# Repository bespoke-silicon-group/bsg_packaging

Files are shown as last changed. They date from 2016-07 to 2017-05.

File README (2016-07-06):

In this directory are a bunch of subdirectories, one for each unique package.

Currently there are two packages:

gf
ucsd_bga_332

There is also the common directory, which contains files for constructing padrings, 
including portability files for each process (e.g. tsmc 250) being targeted.

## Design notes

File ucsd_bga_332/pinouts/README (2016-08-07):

A package is generally a passive component with physical geometry, 
basically a set of electrically connected substrate bond pad (SBP) locations, 
and corresponding connections to pins or balls. 

It does not necessarily say anything about the whether those pins
are inputs or outputs, and it could change based on the use of the package.

We call a package combined with this information a "pinout". This 
directory is for holding pinout-specific files.

Currently, we just have the bsg_one pinout, and bsg_two.

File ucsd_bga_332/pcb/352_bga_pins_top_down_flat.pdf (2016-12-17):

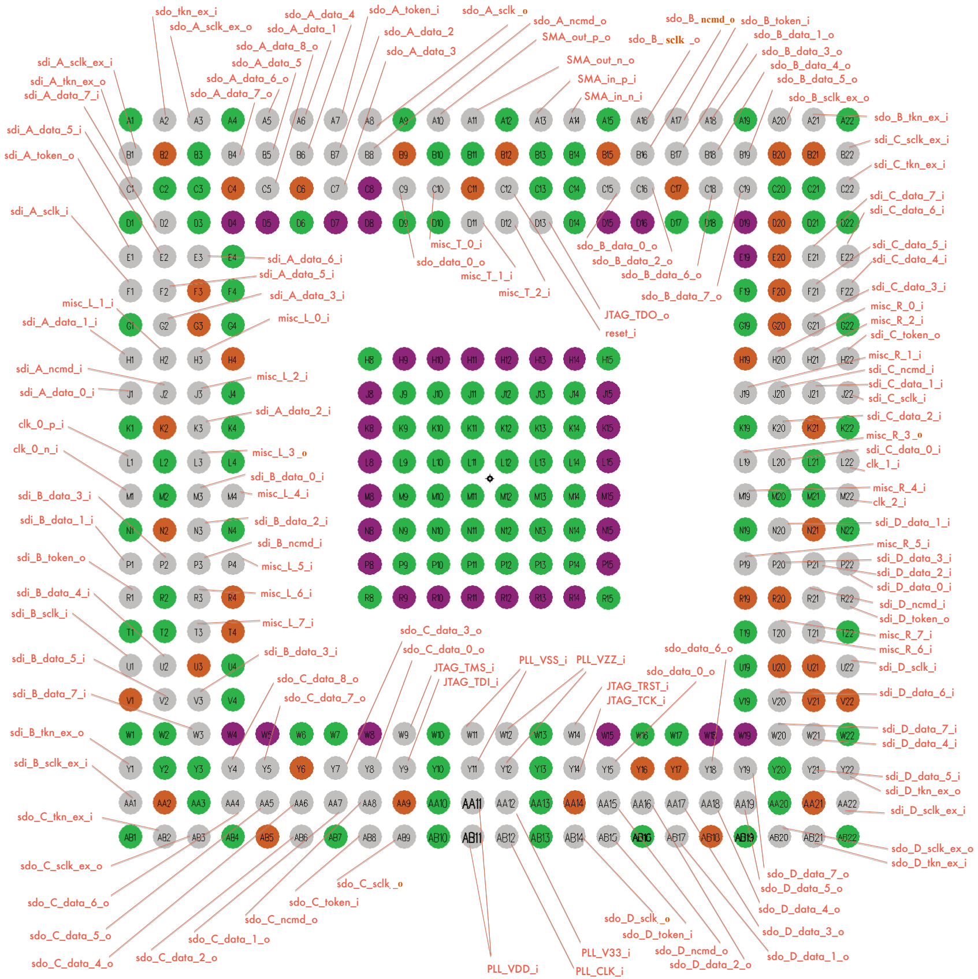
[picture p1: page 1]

sdo_B_tkn_ex_i
sdi_C_sclk_ex_i

sdi_C_tkn_ex_i

sdi_C_data_7_i
sdi_C_data_6_i

sdi_C_data_5_i
sdi_C_data_4_i

sdi_C_data_3_i
misc_R_0_i
misc_R_2_i
sdi_C_token_o
misc_R_1_i
sdi_C_ncmd_i
sdi_C_data_1_i
sdi_C_sclk_i
sdi_C_data_2_i
misc_R_3_i
sdi_C_data_0_i
clk_1_i
misc_R_4_i
clk_2_i
sdi_D_data_1_i
misc_R_5_i
sdi_D_data_3_i
sdi_D_data_2_i
sdi_D_data_0_i
sdi_D_ncmd_i
sdi_D_token_o
misc_R_7_i
misc_R_6_i
sdi_D_sclk_i

sdi_D_data_6_i

sdi_D_data_7_i
sdi_D_data_4_i

sdi_D_data_5_i
sdi_D_tkn_ex_o
sdi_D_sclk_ex_i

sdo_D_sclk_ex_o
sdo_D_tkn_ex_i

sdo_C_data_7_o

sdo_C_data_8_o

sdo_data_6_o
sdo_data_0_o
JTAG_TRST_i
JTAG_TCK_i

PLL_VSS_i PLL_VZZ_i JTAG_TMS_i JTAG_TDI_i

sdo_C_data_0_o

sdo_C_data_3_o

sdo_D_data_7_o
sdo_D_data_5_o

sdo_B_data_7_o

sdo_B_data_6_o

sdo_B_data_2_o

sdo_B_data_0_o

sdo_B_sclk_ex_o

sdo_B_data_3_o

sdo_B_data_5_o

sdo_B_data_4_o

sdo_B_data_1_o

sdo_B_token_i
sdo_B_ncmd_o

sdo_B_sclk_i

SMA_in_n_i

SMA_in_p_i

SMA_out_n_o

SMA_out_p_o

sdo_A_sclk_i
sdo_A_ncmd_o

sdo_A_token_i
sdo_A_data_2
sdo_A_data_3

sdo_A_data_4
sdo_A_data_1

sdo_A_data_5
sdo_A_data_6_o

sdo_A_data_8_o

sdo_A_data_7_o

sdo_A_sclk_ex_o

sdo_tkn_ex_i

JTAG_TDO_o
reset_i

misc_T_2_i

misc_T_1_i

misc_T_0_i
sdo_data_0_o

sdi_A_sclk_ex_i
sdi_A_tkn_ex_o
sdi_A_data_7_i

sdi_A_data_6_i

sdi_A_data_5_i

sdi_A_token_o

sdi_A_data_5_i

sdi_A_sclk_i

sdi_A_data_3_i

sdi_A_data_1_i

misc_L_1_i
misc_L_0_i

misc_L_2_i sdi_A_ncmd_i
sdi_A_data_0_i
sdi_A_data_2_i
clk_0_p_i
clk_0_n_i | misc_L_3_i
| misc_L_4_i

sdi_B_data_0_i

sdi_B_data_2_i

sdi_B_data_3_i

sdi_B_data_1_i
sdi_B_ncmd_i
misc_L_5_i sdi_B_token_o

misc_L_6_i
misc_L_7_i sdi_B_sclk_i

sdi_B_data_4_i

sdi_B_data_5_i | sdi_B_data_3_i

sdi_B_data_7_i

sdi_B_tkn_ex_o

sdi_B_sclk_ex_i

sdo_C_tkn_ex_i

sdo_C_sclk_ex_o

sdo_C_data_6_o

sdo_C_data_5_o
sdo_C_data_4_o sdo_C_data_2_o sdo_C_data_1_o

sdo_C_ncmd_o

sdo_C_token_i

sdo_C_sclk_i

sdo_D_data_4_o
sdo_D_data_3_o

sdo_D_data_1_o sdo_D_data_2_o

sdo_D_ncmd_o

sdo_D_token_i

sdo_D_sclk_i

PLL_CLK_i

PLL_V33_i
PLL_VDD_i

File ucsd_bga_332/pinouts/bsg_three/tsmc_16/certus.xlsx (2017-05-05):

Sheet: MPW2
Order | Approx | Fixed I/O | Fixed I/O Name | Top Row (→) | Left (↑) | Bottom (←) | Right (↓)
1 | 48.09230769 | DVDD | DVDD_1 | DVDD_T_1 | DVDD_L_1 | DVDDTIE_B_1 | DVDD_R_8
2 | 96.18461538 | DVSS | DVSS_1 | DVSS_T_1 | DVSS_L_1 | DVSS_B_1 | DVSS_R_8 | Notes:
3 | 144.2769231 | VDD | VDD_1 | VDD_T_1 | VDD_L_1 | VDD_B_1 | VDD_R_10 | 1) Removed JTAG on the bottom due to congestion. Moved to the Right side
4 | 192.3692308 | VSS | VSS_1 | VSS_T_1 | VSS_L_1 | VSS_B_1 | VSS_R_10 | 2) PG pairs cannot be "moved" due to fixed bump routing
5 | 240.4615385 | SIG | SIG_1 | sdo_A_data_7_o | sdi_B_data_0_i | PLL_1_CLK_SEL_i | sdi_C_data_7_i | 3) Sectioned portions of the IO Ring must have PVDD/PVSS + PDVDD/PDVSS pairs close to both sides
6 | 288.5538462 | SIG | SIG_2 |  | LDO_SPI_RST_i | PLL_2_CLK_SEL_i |  | 4) Some Cells for the PLL SPI signals are not in the isolated domain
7 | 336.6461538 | SIG | SIG_3 |  | sdi_B_data_1_i |  | sdi_C_data_6_i | 5) PLL and LDO signal names are temporary. PLL domain cells must start with PLL_*
8 | 384.7384615 | SIG | SIG_4 | sdo_A_data_6_o |  | PLL_3_CLK_SEL_i
9 | 432.8307692 | SIG | SIG_5 | DVDD_SIG_T_1 | DVDD_SIG_L_1 | DVDD_SIG_B_1 | DVDD_SIG_R_1
10 | 480.9230769 | SIG | SIG_6 | DVSS_SIG_T_1 | DVSS_SIG_L_1 | DVSS_SIG_B_1 | DVSS_SIG_R_1
11 | 529.0153846 | SIG | SIG_7 |  |  | PLL_1_SDO_o
12 | 577.1076923 | SIG | SIG_8 | sdo_A_data_5_o | sdi_B_data_2_i | PLL_1_SDI_i | sdi_C_data_5_i
13 | 625.2 | SIG | SIG_9
14 | 673.2923077 | SIG | SIG_10 |  | sdi_B_data_3_i | PLL_1_CS_i | sdi_C_data_4_i
16 | 769.4769231 | VSS | VSS_2 | VSS_T_2 | VSS_L_2 | VSS_B_2 | VSS_R_9
15 | 721.3846154 | VDD | VDD_2 | VDD_T_2 | VDD_L_2 | VDD_B_2 | VDD_R_9
17 | 817.5692308 | SIG | SIG_11 |  | sdi_B_sclk_i | PLL_2_SDO_o | sdi_C_sclk_i
18 | 865.6615385 | SIG | SIG_12 |  | sdi_B_token_o |  | sdi_C_token_o
20 | 961.8461538 | DVSS | DVSS_2 | DVSS_T_2 | DVSS_L_2 | DVSS_B_2 | DVDD_R_7
19 | 913.7538462 | DVDD | DVDD_2 | DVDD_T_2 | DVDD_L_2 | DVDD_B_2 | DVSS_R_7
21 | 1009.938462 | SIG | SIG_13 | sdo_A_data_4_o |  | PLL_2_SDI_i
22 | 1058.030769 | SIG | SIG_14 | sdo_A_sclk_o | sdi_B_data_4_i |  | sdi_C_data_3_i
23 | 1106.123077 | SIG | SIG_15 |  |  | PLL_2_CS_i
24 | 1154.215385 | SIG | SIG_16 |  | sdi_B_data_5_i |  | sdi_C_data_2_i
25 | 1202.307692 | SIG | SIG_17 | sdo_A_token_i |  | PLL_3_SDO_o
26 | 1250.4 | SIG | SIG_18 | DVSS_SIG_T_2 | DVSS_SIG_L_2 | DVSS_SIG_B_2 | DVSS_SIG_R_2
27 | 1298.492308 | SIG | SIG_19 | DVDD_SIG_T_2 | DVDD_SIG_L_2 | DVDD_SIG_B_2 | DVDD_SIG_R_2
29 | 1394.676923 | VSS | VSS_3 | VSS_T_3 | VSS_L_3 | VSS_B_3 | VSS_R_8
28 | 1346.584615 | VDD | VDD_3 | VDD_T_3 | VDD_L_3 | VDD_B_3 | VDD_R_8
30 | 1442.769231 | SIG | SIG_20 |  | sdi_B_data_6_i | PLL_3_SDI_i | sdi_C_data_1_i
31 | 1490.861538 | SIG | SIG_21
32 | 1538.953846 | SIG | SIG_22 |  | sdi_B_data_7_i | PLL_3_CS_i | sdi_C_data_0_i
33 | 1587.046154 | SIG | SIG_23
34 | 1635.138462 | SIG | SIG_24 |  | sdi_B_ncmd_i | PLL_SCLK_i | sdi_C_ncmd_i
35 | 1683.230769 | SIG | SIG_25 |  |  | PLL_1_CLK_BKP_i
36 | 1731.323077 | SIG | SIG_26 | sdo_A_data_3_o |  | PLL_2_CLK_BKP_i | sdo_D_ncmd_o
38 | 1827.507692 | VSS | VSS_4 | VSS_T_4 | VSS_L_4 | VSS_B_4 | VDD_R_7
37 | 1779.415385 | VDD | VDD_4 | VDD_T_4 | VDD_L_4 | VDD_B_4 | VSS_R_7
39 | 1875.6 | SIG | SIG_27 |  | sdo_C_data_0_o | PLL_3_CLK_BKP_i | sdo_D_data_7_o
40 | 1923.692308 | DVDD | DVDD_3 | DVDD_T_3 | DVDD_L_3 | DVDD_B_3 | DVDD_R_6
41 | 1971.784615 | DVSS | DVSS_3 | DVSS_T_3 | DVSS_L_3 | DVSS_B_3 | DVSS_R_6
42 | 2019.876923 | SIG_D | SIG_D_28 | sdo_A_data_2_o | sdo_C_data_1_o | PLL_SECTION_1_REF_i | sdo_D_data_6_o
43 | 2067.969231 | SIG | SIG_29 |  |  | PLL_SECTION_VDD_SIG_1
44 | 2116.061538 | SIG | SIG_30 | sdo_A_data_1_o | sdo_C_data_2_o | PLL_SECTION_VSS_SIG_1 | sdo_D_data_5_o
45 | 2164.153846 | DVDD | DVDD_4 | DVDD_T_4 | DVDD_L_4 | PLL_SECTION_DVDDTIE_B_4 | DVDD_R_5
46 | 2212.246154 | DVSS | DVSS_4 | DVSS_T_4 | DVSS_L_4 | PLL_SECTION_DVSS_B_4 | DVSS_R_5
47 | 2260.338462 | SIG_D | SIG_D_31 | sdo_A_data_0_o | sdo_C_data_3_o | PLL_SECTION_1_TST_o | sdo_D_data_4_o
48 | 2308.430769 | SIG | SIG_32 |  |  | PLL_SECTION_1_RST_i
49 | 2356.523077 | SIG | SIG_33 | sdo_A_ncmd_o |  | PLL_SECTION_2_REF_i
50 | 2404.615385 | VDD | VDD_5 | VDD_T_5 | VDD_L_5 | X | VSS_R_6 | Bottom removed because we need to isolate VDD_PLL
51 | 2452.707692 | VSS | VSS_5 | VSS_T_5 | VSS_L_5 | X | VDD_R_6 | Bottom removed because we need to isolate VSS_PLL
52 | 2500.8 | SIG | SIG_34 | reset_i | sdo_C_sclk_o | PLL_SECTION_2_TST_o | sdo_D_token_i
53 | 2548.892308 | SIG | SIG_35 |  | sdo_C_token_i | PLL_SECTION_2_RST_i | sdo_D_sclk_o
55 | 2645.076923 | VDD | VDD_6 | VDD_T_6 | VDD_L_6 | X | VSS_R_5 | Bottom removed because we need to isolate VDD_PLL
54 | 2596.984615 | VSS | VSS_6 | VSS_T_6 | VSS_L_6 | X | VDD_R_5 | Bottom removed because we need to isolate VSS_PLL
56 | 2693.169231 | SIG | SIG_36 | sdo_B_ncmd_o
57 | 2741.261538 | SIG | SIG_37 |  |  | PLL_SECTION_3_RST_i
58 | 2789.353846 | SIG_D | SIG_D_38 | sdo_B_data_0_o | sdo_C_data_4_o | PLL_SECTION_3_REF_i | sdo_D_data_3_o
59 | 2837.446154 | DVSS | DVSS_5 | DVSS_T_5 | DVSS_L_5 | PLL_SECTION_DVSS_B_5 | DVSS_R_4
60 | 2885.538462 | DVDD | DVDD_5 | DVDD_T_5 | DVDD_L_5 | PLL_SECTION_DVDD_B_5 | DVDD_R_4
61 | 2933.630769 | SIG | SIG_39 | sdo_B_data_1_o | sdo_C_data_5_o | PLL_SECTION_3_TST_o | sdo_D_data_2_o
62 | 2981.723077 | SIG | SIG_40 |  |  | PLL_SECTION_VDD_SIG_2
63 | 3029.815385 | SIG_D | SIG_D_41 | sdo_B_data_2_o | sdo_C_data_6_o | PLL_SECTION_VSS_SIG_2 | sdo_D_data_1_o
64 | 3077.907692 | DVSS | DVSS_6 | DVSS_T_6 | DVSS_L_6 | PLL_SECTION_DVSS_B_6 | DVSS_R_3
65 | 3126 | DVDD | DVDD_6 | DVDD_T_6 | DVDD_L_6 | PLL_SECTION_DVDD_B_6 | DVDD_R_3
66 | 3174.092308 | SIG | SIG_42 |  | sdo_C_data_7_o | LDO_SECTION_VDD_LOAD_i | sdo_D_data_0_o
67 | 3222.184615 | VSS | VSS_7 | VSS_T_7 | VSS_L_7 | LDO_SECTION_VSS_B_7 | VDD_R_4
68 | 3270.276923 | VDD | VDD_7 | VDD_T_7 | VDD_L_7 | LDO_SECTION_VDD_B_7 | VSS_R_4
69 | 3318.369231 | SIG | SIG_43 | sdo_B_data_3_o | sdo_C_ncmd_o | LDO_SECTION_PAVSS_SIG_1
70 | 3366.461538 | SIG | SIG_44 |  |  | LDO_SECTION_PAVDD_SIG_1
71 | 3414.553846 | SIG | SIG_45 |  | sdi_A_ncmd_i | LDO_SECTION_VL_i | sdi_D_ncmd_i
72 | 3462.646154 | SIG | SIG_46 |  |  | LDO_SECTION_VB_RING_i
73 | 3510.738462 | SIG | SIG_47 |  | sdi_A_data_0_i | LDO_SECTION_VDDIO | sdi_D_data_7_i
74 | 3558.830769 | SIG | SIG_48 |  |  | LDO_SECTION_PAVSS_SIG_2
75 | 3606.923077 | SIG | SIG_49 |  | sdi_A_data_1_i | LDO_SECTION_PAVDD_SIG_2 | sdi_D_data_6_i
77 | 3703.107692 | VDD | VDD_8 | VDD_T_8 | VDD_L_8 | LDO_SECTION_VDD_B_8 | VDD_R_3
76 | 3655.015385 | VSS | VSS_8 | VSS_T_8 | VSS_L_8 | LDO_SECTION_VSS_B_8 | VSS_R_3
78 | 3751.2 | SIG | SIG_50 | DVDD_SIG_T_3 | DVDD_SIG_L_3 | LDO_SECTION_VCAL_HH_i | DVDD_SIG_R_3
79 | 3799.292308 | SIG | SIG_51 | DVSS_SIG_T_3 | DVSS_SIG_L_3 | LDO_SECTION_VCAL_LL_i | DVSS_SIG_R_3
80 | 3847.384615 | SIG | SIG_52 | sdo_B_token_i |  | LDO_SECTION_VREFH_i
81 | 3895.476923 | SIG | SIG_53 |  | sdi_A_data_2_i | LDO_SECTION_VREFL_i | sdi_D_data_5_i
82 | 3943.569231 | SIG | SIG_54 |  |  | LDO_SECTION_VDDC
83 | 3991.661538 | SIG | SIG_55 | sdo_B_sclk_o | sdi_A_data_3_i | LDO_SECTION_PAVSS_SIG_3 | sdi_D_data_4_i
84 | 4039.753846 | SIG | SIG_56 | sdo_B_data_4_o |  | LDO_SECTION_PAVDD_SIG_3
85 | 4087.846154 | DVSS | DVSS_7 | DVSS_T_7 | DVSS_L_7 | DVSS_B_7 | DVDD_R_2
86 | 4135.938462 | DVDD | DVDD_7 | DVDD_T_7 | DVDD_L_7 | DVDD_B_7 | DVSS_R_2
87 | 4184.030769 | SIG | SIG_57 |  | sdi_A_token_o | LDO_CLKOV64_o | sdi_D_token_o
88 | 4232.123077 | SIG | SIG_58 |  | sdi_A_sclk_i | LDO_ENH_o | sdi_D_sclk_i
90 | 4328.307692 | VDD | VDD_9 | VDD_T_9 | VDD_L_9 | VDD_B_9 | VDD_R_2
89 | 4280.215385 | VSS | VSS_9 | VSS_T_9 | VSS_L_9 | VSS_B_9 | VSS_R_2
91 | 4376.4 | SIG | SIG_59 |  |  | LDO_ENHH_o
92 | 4424.492308 | SIG | SIG_60 |  | sdi_A_data_4_i | LDO_ENL_o | sdi_D_data_3_i
93 | 4472.584615 | SIG | SIG_61 | sdo_B_data_5_o |  | LDO_ENLL_o
94 | 4520.676923 | SIG | SIG_62 |  | sdi_A_data_5_i | LDO_EXT_SAM_i | sdi_D_data_2_i
95 | 4568.769231 | SIG | SIG_63 | DVDD_SIG_T_4 | DVDD_SIG_L_4 | LDO_CLK_LOAD_i | DVDD_SIG_R_4
96 | 4616.861538 | SIG | SIG_64 | DVSS_SIG_T_4 | DVSS_SIG_L_4 | LDO_CLK_REF_i | DVSS_SIG_R_4
97 | 4664.953846 | SIG | SIG_65 | sdo_B_data_6_o |  | LDO_RSTIN_i
98 | 4713.046154 | SIG | SIG_66 |  | sdi_A_data_6_i | LDO_SPI_CLK_i | sdi_D_data_1_i
99 | 4761.138462 | SIG | SIG_67 |  |  | LDO_SPI_IN_i
100 | 4809.230769 | SIG | SIG_68 | sdo_B_data_7_o | sdi_A_data_7_i | X | sdi_D_data_0_i | Removed beacause MOSIS requested one less bump
101 | 4857.323077 | VSS | VSS_10 | VSS_T_10 | VSS_L_10 | VSS_B_10 | VSS_R_1
102 | 4905.415385 | VDD | VDD_10 | VDD_T_10 | VDD_L_10 | VDD_B_10 | VDD_R_1
103 | 4953.507692 | DVSS | DVSS_8 | DVSS_T_8 | DVSS_L_8 | DVSS_B_8 | DVSS_R_1
104 | 5001.6 | DVDD | DVDD_8 | DVDD_T_8 | DVDD_L_8 | DVDD_B_8 | DVDD_R_1
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

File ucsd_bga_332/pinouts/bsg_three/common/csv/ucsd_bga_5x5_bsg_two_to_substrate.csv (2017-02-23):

Die# | Subs# | Net Name | Pad Name | Side | Layer | Length | Bond Angle | Die X | Die Y | Subs X | Subs Y | Comments
1 | 1 | VSS | VSS_L_0 | Left | Outside | 1.318758886 | 44.84639238 | -2.465 | 1.93 | -3.4 | 2.86
2 | 2 | V33 | V33_L_0 | Left | Outside | 3.319980917 | 44.33942871 | -2.465 | 1.805 | -4.83949 | 4.12536
3 | 3 | VSS | VZZ_L_0 | Left | Outside | 1.34726575 | 46.05255994 | -2.465 | 1.68 | -3.4 | 2.65
4 | 4 | VDD | VDD_L_0 | Left | Outside | 2.439976287 | 46.4118452 | -2.465 | 1.6 | -4.14729 | 3.36731
5 | 5 | VSS | VSS_L_1 | Left | Outside | 1.292290171 | 43.65398956 | -2.465 | 1.52 | -3.4 | 2.41207
6 | 6 | V33 | V33_L_1 | Left | Outside | 3.334522397 | 42.22326027 | -2.465 | 1.44 | -4.93432 | 3.68087
7 | 7 | sdi_A_sclk_ex_i | sdi_A_sclk_ex_i | Left | Inside | 4.350187934 | 46.39935649 | -2.369 | 1.4 | -5.36901 | 4.55025
8 | 8 | VSS | VZZ_L_1 | Left | Outside | 1.312069678 | 44.55195403 | -2.465 | 1.36 | -3.4 | 2.28049
9 | 9 | sdi_A_tkn_ex_o | sdi_A_tkn_ex_o | Left | Inside | 4.280919345 | 44.08962822 | -2.369 | 1.32 | -5.44378 | 4.29859
10 | 10 | VDD | VDD_L_1 | Left | Outside | 2.368408104 | 41.06781303 | -2.465 | 1.28 | -4.25062 | 2.83593
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

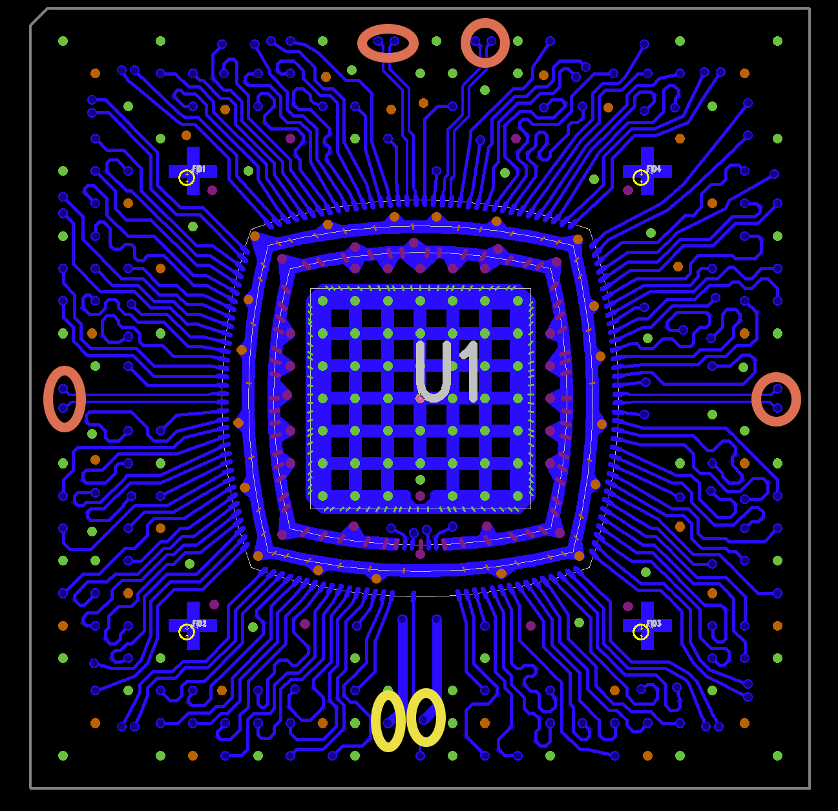
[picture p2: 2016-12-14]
ucsd_bga_332/pcb/for_fab_sierra_proto_express/impedance.png

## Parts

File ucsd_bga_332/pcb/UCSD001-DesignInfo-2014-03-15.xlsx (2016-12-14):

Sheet: Length All
Sort | Die# | SBP X | SBP Y | BGA | BGA X | BGA Y | Net Name | Len Top | Len Bot | Total Subst | Length Wire | Length All | Clk | Freq | Analog | Pair | Group | # | Net 4mm | Clk | Freq | Analog | Pair | Group | Layout Instructions | Class | Die# | Net Name | Length | Angle | Die X | Die Y | Subs X | Subs Y
1 | 43 | -6.1 | -0.12 | M1 | -10.5 | -0.5 | clk_0_n_i | 4.97701 | 0.53852 | 5.52 | 3.77 | 9.28 | 1 | 4000 |  | 1 | Ki | 38 | clk_0_n_i | 1 | 4000 |  | 1 | Ki | Highest prior, outer row, shield | PAIRS | 43 | clk_0_n_i | 3.768 | 1.13295 | -2.2815 | -0.04 | -6.04878 | -0.1145
2 | 41 | -6.1 | 0.15 | L1 | -10.5 | 0.5 | clk_0_p_i | 5.0041 | 0.53852 | 5.54 | 3.77 | 9.31 | 1 | 4000 |  | 1 | Ki | 36 | clk_0_p_i | 1 | 4000 |  | 1 | Ki | Highest prior, outer row, shield | PAIRS | 41 | clk_0_p_i | 3.7686 | 1.65714 | -2.2815 | 0.04 | -6.04849 | 0.14898
3 | 209 | 6.1 | 0.14 | L22 | 10.5 | 0.5 | clk_1_i | 5.00745 | 0.53852 | 5.55 | 3.77 | 9.31 | 1 | 2000 |  |  |  | 184 | clk_1_i | 1 | 2000 |  |  |  | Highest prior, outer row, shield | PAIRS | 209 | clk_1_i | 3.7684 | 1.53286 | 2.2815 | 0.04 | 6.04856 | 0.14081
4 | 207 | 6.1 | -0.14 | M22 | 10.5 | -0.5 | clk_2_i | 4.98537 | 0.53852 | 5.52 | 3.77 | 9.29 | 1 | 2000 |  |  |  | 182 | clk_2_i | 1 | 2000 |  |  |  | Highest prior, outer row, shield | PAIRS | 207 | clk_2_i | 3.7683 | 1.42974 | 2.2815 | -0.04 | 6.04862 | -0.13402
5 | 284 | 0.95 | 6.07 | A14 | 2.5 | 10.5 | SMA_in_n_i | 5.44704 | 0.5831 | 6.03 | 3.80 | 9.83 |  | 4000 |  | 1 | Si | 249 | SMA_in_n_i |  | 4000 |  | 1 | Si | Highest prior, outer row, shield | PAIRS | 284 | SMA_in_n_i | 3.7973 | 10.02959 | 0.28 | 2.2815 | 0.94133 | 6.02077
6 | 286 | 0.68 | 6.09 | A13 | 1.5 | 10.5 | SMA_in_p_i | 5.4541 | 0.53852 | 5.99 | 3.78 | 9.78 |  | 4000 |  | 1 | Si | 251 | SMA_in_p_i |  | 4000 |  | 1 | Si | Highest prior, outer row, shield | PAIRS | 286 | SMA_in_p_i | 3.7828 | 7.16863 | 0.2 | 2.2815 | 0.67205 | 6.03472
7 | 292 | -0.14 | 6.1 | A11 | -0.5 | 10.5 | SMA_out_n_o | 5.29939 | 0.5831 | 5.88 | 3.77 | 9.65 |  | 4000 |  | 1 | So | 257 | SMA_out_n_o |  | 4000 |  | 1 | So | Highest prior, outer row, shield | PAIRS | 292 | SMA_out_n_o | 3.7683 | 1.45927 | -0.04 | 2.2815 | -0.13597 | 6.04861
8 | 294 | -0.41 | 6.09 | A10 | -1.5 | 10.5 | SMA_out_p_o | 5.28192 | 0.53852 | 5.82 | 3.77 | 9.59 |  | 4000 |  | 1 | So | 259 | SMA_out_p_o |  | 4000 |  | 1 | So | Highest prior, outer row, shield | PAIRS | 294 | SMA_out_p_o | 3.7732 | 4.33388 | -0.12 | 2.2815 | -0.40514 | 6.04394
9 | 35 | -6.07 | 0.95 | H1 | -10.5 | 3.5 | sdi_A_data_1_i | 7.11216 | 0.70711 | 7.82 | 3.80 | 11.62 |  |  |  |  | Ai | 30 | sdi_A_data_1_i |  |  |  |  | Ai | Length match datas |  | 35 | sdi_A_data_1_i | 3.797 | 9.98406 | -2.2815 | 0.28 | -6.02095 | 0.93829
10 | 7 | -5.4 | 4.59 | B1 | -10.5 | 9.5 | sdi_A_sclk_ex_i | 7.20275 | 0.5 | 7.70 | 4.41 | 12.11 | 1 | 1000 |  |  | Ai | 2 | sdi_A_sclk_ex_i | 1 | 1000 |  |  | Ai | Second prior, outer\second row | SDX_HIGH | 7 | sdi_A_sclk_ex_i | 4.411 | 45.57627 | -2.2815 | 1.4 | -5.36901 | 4.55025
11 | 27 | -5.97 | 2 | F1 | -10.5 | 5.5 | sdi_A_sclk_i | 7.21692 | 0.53852 | 7.76 | 3.90 | 11.65 | 1 | 1000 |  |  | Ai | 22 | sdi_A_sclk_i | 1 | 1000 |  |  | Ai | Second prior, outer\second row | SDX_HIGH | 27 | sdi_A_sclk_i | 3.8955 | 20.83497 | -2.2815 | 0.6 | -5.92224 | 1.98553
12 | 9 | -5.48 | 4.33 | C1 | -10.5 | 8.5 | sdi_A_tkn_ex_o | 7.08288 | 0.5 | 7.58 | 4.34 | 11.93 | 1 | 1000 |  |  | Ai | 4 | sdi_A_tkn_ex_o | 1 | 1000 |  |  | Ai | Second prior, outer\second row | SDX_HIGH | 9 | sdi_A_tkn_ex_o | 4.3442 | 43.28659 | -2.2815 | 1.32 | -5.44378 | 4.29859
13 | 23 | -5.89 | 2.53 | E1 | -10.5 | 6.5 | sdi_A_token_o | 6.9664 | 0.5831 | 7.55 | 3.97 | 11.52 | 1 | 1000 |  |  | Ai | 18 | sdi_A_token_o | 1 | 1000 |  |  | Ai | Second prior, outer\second row | SDX_HIGH | 23 | sdi_A_token_o | 3.9694 | 26.09026 | -2.2815 | 0.76 | -5.84645 | 2.5057
14 | 17 | -5.74 | 3.31 | F2 | -9.5 | 5.5 | sdi_A_data_4_i | 6.80715 | 0.70711 | 7.51 | 4.11 | 11.62 |  |  |  |  | Ai | 12 | sdi_A_data_4_i |  |  |  |  | Ai | Length match datas |  | 17 | sdi_A_data_4_i | 4.109 | 33.70307 | -2.2815 | 1 | -5.69992 | 3.28007
15 | 11 | -5.55 | 4.08 | D2 | -9.5 | 7.5 | sdi_A_data_7_i | 6.42752 | 0.70711 | 7.13 | 4.28 | 11.42 |  |  |  |  | Ai | 6 | sdi_A_data_7_i |  |  |  |  | Ai | Length match datas |  | 11 | sdi_A_data_7_i | 4.2805 | 40.9541 | -2.2815 | 1.24 | -5.51428 | 4.04567
16 | 13 | -5.62 | 3.82 | E3 | -8.5 | 6.5 | sdi_A_data_6_i | 6.36536 | 0.70711 | 7.07 | 4.22 | 11.29 |  |  |  |  | Ai | 8 | sdi_A_data_6_i |  |  |  |  | Ai | Length match datas |  | 13 | sdi_A_data_6_i | 4.22 | 38.57899 | -2.2815 | 1.16 | -5.58048 | 3.79156
17 | 37 | -6.08 | 0.68 | J1 | -10.5 | 2.5 | sdi_A_data_0_i | 6.4131 | 0.70711 | 7.12 | 3.78 | 10.90 |  |  |  |  | Ai | 32 | sdi_A_data_0_i |  |  |  |  | Ai | Length match datas |  | 37 | sdi_A_data_0_i | 3.7831 | 7.21989 | -2.2815 | 0.2 | -6.03457 | 0.67545
18 | 19 | -5.8 | 3.05 | G2 | -9.5 | 4.5 | sdi_A_data_3_i | 6.26687 | 0.70711 | 6.97 | 4.06 | 11.03 |  |  |  |  | Ai | 14 | sdi_A_data_3_i |  |  |  |  | Ai | Length match datas |  | 19 | sdi_A_data_3_i | 4.0588 | 31.20401 | -2.2815 | 0.92 | -5.75312 | 3.02282
19 | 31 | -6.03 | 1.48 | J2 | -9.5 | 2.5 | sdi_A_ncmd_i | 6.25182 | 0.70711 | 6.96 | 3.84 | 10.80 |  |  |  |  | Ai | 26 | sdi_A_ncmd_i |  |  |  |  | Ai |  |  | 31 | sdi_A_ncmd_i | 3.8378 | 15.45793 | -2.2815 | 0.44 | -5.98043 | 1.46288
20 | 15 | -5.68 | 3.57 | E2 | -9.5 | 6.5 | sdi_A_data_5_i | 6.00242 | 0.70711 | 6.71 | 4.16 | 10.87 |  |  |  |  | Ai | 10 | sdi_A_data_5_i |  |  |  |  | Ai | Length match datas |  | 15 | sdi_A_data_5_i | 4.1628 | 36.16173 | -2.2815 | 1.08 | -5.64236 | 3.53634
21 | 33 | -6.05 | 1.21 | K3 | -8.5 | 1.5 | sdi_A_data_2_i | 5.91035 | 0.64031 | 6.55 | 3.82 | 10.37 |  |  |  |  | Ai | 28 | sdi_A_data_2_i |  |  |  |  | Ai | Length match datas |  | 33 | sdi_A_data_2_i | 3.8152 | 12.73135 | -2.2815 | 0.36 | -6.00291 | 1.2008
22 | 77 | -5.41 | -4.58 | AA1 | -10.5 | -9.5 | sdi_B_sclk_ex_i | 7.10187 | 0.70711 | 7.81 | 4.41 | 12.22 | 1 | 1000 |  |  | Bi | 72 | sdi_B_sclk_ex_i | 1 | 1000 |  |  | Bi | Second prior, outer\second row | SDX_HIGH | 77 | sdi_B_sclk_ex_i | 4.41 | 45.55282 | -2.2815 | -1.4 | -5.36961 | -4.54828
23 | 71 | -5.62 | -3.81 | V3 | -8.5 | -6.5 | sdi_B_data_6_i | 7.04943 | 0.70711 | 7.76 | 4.21 | 11.97 |  |  |  |  | Bi | 66 | sdi_B_data_6_i |  |  |  |  | Bi | Length match datas |  | 71 | sdi_B_data_6_i | 4.2149 | 38.42791 | -2.2815 | -1.16 | -5.58344 | -3.77971
24 | 67 | -5.75 | -3.29 | U2 | -9.5 | -5.5 | sdi_B_data_4_i | 6.68846 | 0.64031 | 7.33 | 4.10 | 11.43 |  |  |  |  | Bi | 62 | sdi_B_ncmd_i |  |  |  |  | Bi |  |  | 67 | sdi_B_ncmd_i | 4.1025 | 33.47013 | -2.2815 | -1 | -5.70367 | -3.26252
25 | 47 | -6.09 | -0.65 | M3 | -8.5 | -0.5 | sdi_B_data_0_i | 6.90242 | 0.70711 | 7.61 | 3.78 | 11.39 |  |  |  |  | Bi | 42 | sdi_B_data_0_i |  |  |  |  | Bi | Length match datas |  | 47 | sdi_B_data_0_i | 3.7804 | 6.70874 | -2.2815 | -0.2 | -6.03599 | -0.64163
26 | 75 | -5.48 | -4.33 | Y1 | -10.5 | -8.5 | sdi_B_tkn_ex_o | 7.04779 | 0.57009 | 7.62 | 4.34 | 11.96 | 1 | 1000 |  |  | Bi | 70 | sdi_B_tkn_ex_o | 1 | 1000 |  |  | Bi | Second prior, outer\second row | SDX_HIGH | 75 | sdi_B_tkn_ex_o | 4.3416 | 43.2203 | -2.2815 | -1.32 | -5.44534 | -4.29315
27 | 73 | -5.56 | -4.07 | W3 | -8.5 | -7.5 | sdi_B_data_7_i | 6.83637 | 0.70711 | 7.54 | 4.28 | 11.82 |  |  |  |  | Bi | 68 | sdi_B_data_7_i |  |  |  |  | Bi | Length match datas |  | 73 | sdi_B_data_7_i | 4.2765 | 40.84518 | -2.2815 | -1.24 | -5.51662 | -4.03694
28 | 69 | -5.69 | -3.55 | V2 | -9.5 | -6.5 | sdi_B_data_5_i | 6.70981 | 0.70711 | 7.42 | 4.16 | 11.57 |  |  |  |  | Bi | 64 | sdi_B_data_5_i |  |  |  |  | Bi | Length match datas |  | 69 | sdi_B_data_5_i | 4.1569 | 35.96923 | -2.2815 | -1.08 | -5.64579 | -3.52154
29 | 51 | -6.05 | -1.18 | N3 | -8.5 | -1.5 | sdi_B_data_2_i | 6.6916 | 0.70711 | 7.40 | 3.81 | 11.21 |  |  |  |  | Bi | 46 | sdi_B_data_2_i |  |  |  |  | Bi | Length match datas |  | 51 | sdi_B_data_2_i | 3.8106 | 12.25 | -2.2815 | -0.36 | -6.00535 | -1.16853
30 | 55 | -6.01 | -1.71 | P3 | -8.5 | -2.5 | sdi_B_ncmd_i | 6.98161 | 0.70711 | 7.69 | 3.86 | 11.55 |  |  |  |  | Bi | 50 | sdi_B_data_4_i |  |  |  |  | Bi | Length match datas |  | 55 | sdi_B_data_4_i | 3.8585 | 17.72389 | -2.2815 | -0.52 | -5.95682 | -1.69463
31 | 63 | -5.85 | -2.77 | U1 | -10.5 | -5.5 | sdi_B_sclk_i | 6.55244 | 0.70711 | 7.26 | 4.00 | 11.26 | 1 | 1000 |  |  | Bi | 58 | sdi_B_sclk_i | 1 | 1000 |  |  | Bi | Second prior, outer\second row | SDX_HIGH | 63 | sdi_B_sclk_i | 4.005 | 28.35634 | -2.2815 | -0.84 | -5.80598 | -2.74221
32 | 59 | -5.94 | -2.24 | R1 | -10.5 | -3.5 | sdi_B_token_o | 6.43574 | 0.70711 | 7.14 | 3.92 | 11.07 | 1 | 1000 |  |  | Bi | 54 | sdi_B_token_o | 1 | 1000 |  |  | Bi | Second prior, outer\second row | SDX_HIGH | 59 | sdi_B_token_o | 3.9235 | 23.10099 | -2.2815 | -0.68 | -5.89037 | -2.21939
33 | 49 | -6.07 | -0.91 | P1 | -10.5 | -2.5 | sdi_B_data_1_i | 6.32065 | 0.70711 | 7.03 | 3.79 | 10.82 |  |  |  |  | Bi | 44 | sdi_B_data_1_i |  |  |  |  | Bi | Length match datas |  | 49 | sdi_B_data_1_i | 3.7933 | 9.4858 | -2.2815 | -0.28 | -6.0229 | -0.90514
34 | 53 | -6.03 | -1.44 | P2 | -9.5 | -2.5 | sdi_B_data_3_i | 6.16143 | 0.64031 | 6.80 | 3.83 | 10.63 |  |  |  |  | Bi | 48 | sdi_B_data_3_i |  |  |  |  | Bi | Length match datas |  | 53 | sdi_B_data_3_i | 3.8324 | 14.99729 | -2.2815 | -0.44 | -5.98332 | -1.43171
35 | 213 | 6.08 | 0.7 | L20 | 8.5 | 0.5 | sdi_C_data_0_i | 6.4197 | 0.70711 | 7.13 | 3.78 | 10.91 |  |  |  |  | Ci | 188 | sdi_C_data_0_i |  |  |  |  | Ci | Length match datas |  | 213 | sdi_C_data_0_i | 3.7843 | 7.44021 | 2.2815 | 0.2 | 6.03394 | 0.69003
36 | 231 | 5.77 | 3.17 | G21 | 9.5 | 4.5 | sdi_C_data_3_i | 6.40831 | 0.70711 | 7.12 | 4.10 | 11.22 |  |  |  |  | Ci | 206 | sdi_C_data_3_i |  |  |  |  | Ci | Length match datas |  | 231 | sdi_C_data_3_i | 4.1006 | 32.76359 | 2.2815 | 0.92 | 5.72976 | 3.13915
37 | 243 | 5.35 | 4.77 | B22 | 10.5 | 9.5 | sdi_C_sclk_ex_i | 6.53498 | 0.56569 | 7.10 | 4.50 | 11.60 | 1 | 1000 |  |  | Ci | 218 | sdi_C_sclk_ex_i | 1 | 1000 |  |  | Ci | Second prior, outer\second row | SDX_HIGH | 243 | sdi_C_sclk_ex_i | 4.5038 | 47.69986 | 2.2815 | 1.4 | 5.3126 | 4.73112
38 | 223 | 5.96 | 2.08 | J22 | 10.5 | 2.5 | sdi_C_sclk_i | 6.3368 | 0.70711 | 7.04 | 3.91 | 10.96 | 1 | 1000 |  |  | Ci | 198 | sdi_C_sclk_i | 1 | 1000 |  |  | Ci | Second prior, outer\second row | SDX_HIGH | 223 | sdi_C_sclk_i | 3.9128 | 21.86162 | 2.2815 | 0.6 | 5.91296 | 2.05701
39 | 233 | 5.71 | 3.44 | F22 | 10.5 | 5.5 | sdi_C_data_4_i | 6.29682 | 0.70711 | 7.00 | 4.16 | 11.16 |  |  |  |  | Ci | 208 | sdi_C_data_4_i |  |  |  |  | Ci | Length match datas |  | 233 | sdi_C_data_4_i | 4.1583 | 35.37642 | 2.2815 | 1 | 5.67204 | 3.40743
40 | 235 | 5.65 | 3.71 | F21 | 9.5 | 5.5 | sdi_C_data_5_i | 6.23191 | 0.70711 | 6.94 | 4.22 | 11.16 |  |  |  |  | Ci | 210 | sdi_C_data_5_i |  |  |  |  | Ci | Length match datas |  | 235 | sdi_C_data_5_i | 4.22 | 37.94075 | 2.2815 | 1.08 | 5.60957 | 3.67464
41 | 239 | 5.51 | 4.23 | E21 | 9.5 | 6.5 | sdi_C_data_7_i | 6.18047 | 0.70711 | 6.89 | 4.35 | 11.24 |  |  |  |  | Ci | 214 | sdi_C_data_7_i |  |  |  |  | Ci | Length match datas |  | 239 | sdi_C_data_7_i | 4.3512 | 42.83125 | 2.2815 | 1.24 | 5.47252 | 4.19816
42 | 237 | 5.58 | 3.97 | E22 | 10.5 | 6.5 | sdi_C_data_6_i | 6.28305 | 0.56569 | 6.85 | 4.28 | 11.13 |  |  |  |  | Ci | 212 | sdi_C_data_6_i |  |  |  |  | Ci | Length match datas |  | 237 | sdi_C_data_6_i | 4.2824 | 40.36962 | 2.2815 | 1.16 | 5.54418 | 3.93377
43 | 217 | 6.05 | 1.25 | K20 | 8.5 | 1.5 | sdi_C_data_2_i | 6.20916 | 0.57009 | 6.78 | 3.82 | 10.60 |  |  |  |  | Ci | 192 | sdi_C_data_2_i |  |  |  |  | Ci | Length match datas |  | 217 | sdi_C_data_2_i | 3.8208 | 13.28778 | 2.2815 | 0.36 | 6 | 1.23818
44 | 219 | 6.02 | 1.53 | J20 | 8.5 | 2.5 | sdi_C_ncmd_i | 6.06907 | 0.56569 | 6.63 | 3.85 | 10.48 |  |  |  |  | Ci | 194 | sdi_C_ncmd_i |  |  |  |  | Ci | Length match datas |  | 219 | sdi_C_ncmd_i | 3.8466 | 16.17655 | 2.2815 | 0.44 | 5.97579 | 1.51165
45 | 215 | 6.07 | 0.97 | J21 | 9.5 | 2.5 | sdi_C_data_1_i | 5.91075 | 0.70711 | 6.62 | 3.80 | 10.42 |  |  |  |  | Ci | 190 | sdi_C_data_1_i |  |  |  |  | Ci | Length match datas |  | 215 | sdi_C_data_1_i | 3.8 | 10.37406 | 2.2815 | 0.28 | 6.01938 | 0.96428
46 | 227 | 5.88 | 2.62 | H22 | 10.5 | 3.5 | sdi_C_token_o | 5.88504 | 0.70711 | 6.59 | 4.00 | 10.59 | 1 | 1000 |  |  | Ci | 202 | sdi_C_token_o | 1 | 1000 |  |  | Ci | Second prior, outer\second row | SDX_HIGH | 227 | sdi_C_token_o | 3.9979 | 27.3985 | 2.2815 | 0.76 | 5.83092 | 2.59973
47 | 241 | 5.43 | 4.51 | C22 | 10.5 | 8.5 | sdi_C_tkn_ex_o | 5.95171 | 0.56569 | 6.52 | 4.43 | 10.94 | 1 | 1000 |  |  | Ci | 216 | sdi_C_tkn_ex_o | 1 | 1000 |  |  | Ci | Second prior, outer\second row | SDX_HIGH | 241 | sdi_C_tkn_ex_o | 4.4275 | 45.33536 | 2.2815 | 1.32 | 5.39387 | 4.46902
48 | 181 | 5.65 | -3.71 | Y21 | 9.5 | -8.5 | sdi_D_data_5_i | 6.91517 | 0.70711 | 7.62 | 4.22 | 11.85 |  |  |  |  | Di | 156 | sdi_D_data_5_i |  |  |  |  | Di | Length match datas |  | 181 | sdi_D_data_5_i | 4.2231 | 38.03394 | 2.2815 | -1.08 | 5.6078 | -3.68196
49 | 173 | 5.34 | -4.79 | AA22 | 10.5 | -9.5 | sdi_D_sclk_ex_i | 7.09268 | 0.5 | 7.59 | 4.51 | 12.11 | 1 | 1000 |  |  | Di | 148 | sdi_D_sclk_ex_i | 1 | 1000 |  |  | Di | Second prior, outer\second row | SDX_HIGH | 173 | sdi_D_sclk_ex_i | 4.5124 | 47.88971 | 2.2815 | -1.4 | 5.30735 | -4.74756
50 | 199 | 6.05 | -1.24 | P21 | 9.5 | -2.5 | sdi_D_data_2_i | 6.80671 | 0.78102 | 7.59 | 3.82 | 11.41 |  |  |  |  | Di | 174 | sdi_D_data_2_i |  |  |  |  | Di | Length match datas |  | 199 | sdi_D_data_2_i | 3.82 | 13.21058 | 2.2815 | -0.36 | 6.0004 | -1.23299
51 | 177 | 5.5 | -4.25 | W20 | 8.5 | -7.5 | sdi_D_data_7_i | 6.80091 | 0.70711 | 7.51 | 4.36 | 11.87 |  |  |  |  | Di | 152 | sdi_D_data_7_i |  |  |  |  | Di | Length match datas |  | 177 | sdi_D_data_7_i | 4.3603 | 43.06188 | 2.2815 | -1.24 | 5.4672 | -4.21716
52 | 175 | 5.43 | -4.52 | Y22 | 10.5 | -8.5 | sdi_D_tkn_ex_o | 6.97818 | 0.5 | 7.48 | 4.43 | 11.91 | 1 | 1000 |  |  | Di | 150 | sdi_D_tkn_ex_o | 1 | 1000 |  |  | Di | Second prior, outer\second row | SDX_HIGH | 175 | sdi_D_tkn_ex_o | 4.4346 | 45.50089 | 2.2815 | -1.32 | 5.38968 | -4.483
53 | 195 | 6 | -1.8 | R21 | 9.5 | -3.5 | sdi_D_ncmd_i | 6.19212 | 0.70711 | 6.90 | 3.88 | 10.78 |  |  |  |  | Di | 170 | sdi_D_data_4_i |  |  |  |  | Di | Length match datas |  | 195 | sdi_D_data_4_i | 3.8766 | 18.98569 | 2.2815 | -0.52 | 5.94717 | -1.78117
54 | 179 | 5.58 | -3.98 | V20 | 8.5 | -6.5 | sdi_D_data_6_i | 6.54606 | 0.70711 | 7.25 | 4.29 | 11.54 |  |  |  |  | Di | 154 | sdi_D_data_6_i |  |  |  |  | Di | Length match datas |  | 179 | sdi_D_data_6_i | 4.2898 | 40.57277 | 2.2815 | -1.16 | 5.53991 | -3.95011
55 | 201 | 6.07 | -0.97 | N20 | 8.5 | -1.5 | sdi_D_data_1_i | 6.46045 | 0.70711 | 7.17 | 3.80 | 10.97 |  |  |  |  | Di | 176 | sdi_D_data_1_i |  |  |  |  | Di | Length match datas |  | 201 | sdi_D_data_1_i | 3.7993 | 10.28665 | 2.2815 | -0.28 | 6.01974 | -0.95845
56 | 187 | 5.83 | -2.9 | U22 | 10.5 | -5.5 | sdi_D_sclk_i | 6.33266 | 0.70711 | 7.04 | 4.05 | 11.09 | 1 | 1000 |  |  | Di | 162 | sdi_D_sclk_i | 1 | 1000 |  |  | Di | Second prior, outer\second row | SDX_HIGH | 187 | sdi_D_sclk_i | 4.0477 | 30.12872 | 2.2815 | -0.84 | 5.78238 | -2.87174
57 | 191 | 5.92 | -2.35 | R22 | 10.5 | -3.5 | sdi_D_token_o | 6.20389 | 0.70711 | 6.91 | 3.95 | 10.86 | 1 | 1000 |  |  | Di | 166 | sdi_D_token_o | 1 | 1000 |  |  | Di | Second prior, outer\second row | SDX_HIGH | 191 | sdi_D_token_o | 3.9528 | 24.63472 | 2.2815 | -0.68 | 5.8745 | -2.32764
58 | 183 | 5.71 | -3.44 | W21 | 9.5 | -7.5 | sdi_D_data_4_i | 6.57886 | 0.70711 | 7.29 | 4.16 | 11.45 |  |  |  |  | Di | 158 | sdi_D_ncmd_i |  |  |  |  | Di | Length match datas |  | 183 | sdi_D_ncmd_i | 4.1604 | 35.44617 | 2.2815 | -1 | 5.67084 | -3.41279
59 | 203 | 6.08 | -0.69 | P22 | 10.5 | -2.5 | sdi_D_data_0_i | 6.10637 | 0.70711 | 6.81 | 3.78 | 10.60 |  |  |  |  | Di | 178 | sdi_D_data_0_i |  |  |  |  | Di | Length match datas |  | 203 | sdi_D_data_0_i | 3.7838 | 7.345 | 2.2815 | -0.2 | 6.03421 | -0.68373
60 | 197 | 6.03 | -1.52 | P20 | 8.5 | -2.5 | sdi_D_data_3_i | 5.91389 | 0.57009 | 6.48 | 3.85 | 10.33 |  |  |  |  | Di | 172 | sdi_D_data_3_i |  |  |  |  | Di | Length match datas |  | 197 | sdi_D_data_3_i | 3.8458 | 16.11183 | 2.2815 | -0.44 | 5.97622 | -1.50725
61 | 326 | -4.67 | 5.38 | A2 | -9.5 | 10.5 | sdo_A_tkn_ex_i | 6.87208 | 0.5 | 7.37 | 4.44 | 11.81 | 1 | 1000 |  |  | Ao | 291 | sdo_A_tkn_ex_i | 1 | 1000 |  |  | Ao | Second prior, outer\second row | SDX_HIGH | 326 | sdo_A_tkn_ex_i | 4.4396 | 46.40802 | -1.42 | 2.2815 | -4.63544 | 5.34266
62 | 304 | -1.76 | 6 | B8 | -3.5 | 9.5 | sdo_A_ncmd_o | 6.503 | 0.70711 | 7.21 | 3.86 | 11.07 |  |  |  |  | Ao | 269 | sdo_A_ncmd_o |  |  |  |  | Ao |  |  | 304 | sdo_A_ncmd_o | 3.8629 | 18.20432 | -0.54 | 2.2815 | -1.74678 | 5.95101
63 | 298 | -0.95 | 6.07 | A8 | -3.5 | 10.5 | sdo_A_sclk_i | 6.51248 | 0.70711 | 7.22 | 3.80 | 11.02 | 1 | 1000 |  |  | Ao | 263 | sdo_A_sclk_i | 1 | 1000 |  |  | Ao | Second prior, outer\second row | SDX_HIGH | 298 | sdo_A_sclk_i | 3.7975 | 10.05175 | -0.28 | 2.2815 | -0.9428 | 6.02068
64 | 314 | -3.1 | 5.79 | B6 | -5.5 | 9.5 | sdo_A_data_4_o | 6.33858 | 0.7433 | 7.08 | 4.07 | 11.15 |  |  |  |  | Ao | 279 | sdo_A_data_4_o |  |  |  |  | Ao | Length match datas |  | 314 | sdo_A_data_4_o | 4.0664 | 31.65641 | -0.94 | 2.2815 | -3.07414 | 5.74286
65 | 322 | -4.15 | 5.53 | C5 | -6.5 | 8.5 | sdo_A_data_8_o | 6.47998 | 0.70711 | 7.19 | 4.30 | 11.49 |  |  |  |  | Ao | 287 | sdo_A_data_8_o |  |  |  |  | Ao | Length match datas |  | 322 | sdo_A_data_8_o | 4.3011 | 41.67407 | -1.26 | 2.2815 | -4.11974 | 5.49413
66 | 316 | -3.36 | 5.73 | A5 | -6.5 | 10.5 | sdo_A_data_5_o | 6.59244 | 0.56569 | 7.16 | 4.12 | 11.27 |  |  |  |  | Ao | 281 | sdo_A_data_5_o |  |  |  |  | Ao | Length match datas |  | 316 | sdo_A_data_5_o | 4.1166 | 34.12758 | -1.02 | 2.2815 | -3.32954 | 5.68914
67 | 320 | -3.89 | 5.6 | B4 | -7.5 | 9.5 | sdo_A_data_7_o | 6.47852 | 0.70711 | 7.19 | 4.24 | 11.42 |  |  |  |  | Ao | 285 | sdo_A_data_7_o |  |  |  |  | Ao | Length match datas |  | 320 | sdo_A_data_7_o | 4.2369 | 39.23755 | -1.18 | 2.2815 | -3.86 | 5.56311
68 | 324 | -4.41 | 5.46 | A3 | -8.5 | 10.5 | sdo_A_sclk_ex_o | 6.70411 | 0.5 | 7.20 | 4.37 | 11.57 | 1 | 1000 |  |  | Ao | 289 | sdo_A_sclk_ex_o | 1 | 1000 |  |  | Ao | Second prior, outer\second row | SDX_HIGH | 324 | sdo_A_sclk_ex_o | 4.3687 | 44.06428 | -1.34 | 2.2815 | -4.37824 | 5.42064
69 | 302 | -1.49 | 6.03 | A7 | -4.5 | 10.5 | sdo_A_token_i | 6.56633 | 0.5099 | 7.08 | 3.84 | 10.92 | 1 | 1000 |  |  | Ao | 267 | sdo_A_token_i | 1 | 1000 |  |  | Ao | Second prior, outer\second row | SDX_HIGH | 302 | sdo_A_token_i | 3.8406 | 15.69713 | -0.44 | 2.2815 | -1.47909 | 5.97891
70 | 310 | -2.57 | 5.89 | B7 | -4.5 | 9.5 | sdo_A_data_2_o | 6.12606 | 0.70711 | 6.83 | 3.97 | 10.81 |  |  |  |  | Ao | 275 | sdo_A_data_2_o |  |  |  |  | Ao | Length match datas |  | 310 | sdo_A_data_2_o | 3.9723 | 26.3879 | -0.78 | 2.2815 | -2.54546 | 5.83989
71 | 308 | -2.3 | 5.93 | A6 | -5.5 | 10.5 | sdo_A_data_1_o | 6.12222 | 0.56569 | 6.69 | 3.93 | 10.62 |  |  |  |  | Ao | 273 | sdo_A_data_1_o |  |  |  |  | Ao | Length match datas |  | 308 | sdo_A_data_1_o | 3.9315 | 23.69485 | -0.7 | 2.2815 | -2.27992 | 5.88153
72 | 318 | -3.63 | 5.67 | B5 | -6.5 | 9.5 | sdo_A_data_6_o | 5.84948 | 0.70711 | 6.56 | 4.18 | 10.73 |  |  |  |  | Ao | 283 | sdo_A_data_6_o |  |  |  |  | Ao | Length match datas |  | 318 | sdo_A_data_6_o | 4.1762 | 36.75198 | -1.1 | 2.2815 | -3.59885 | 5.62763
73 | 312 | -2.83 | 5.84 | C7 | -4.5 | 8.5 | sdo_A_data_3_o | 5.82107 | 0.70711 | 6.53 | 4.02 | 10.55 |  |  |  |  | Ao | 277 | sdo_A_data_3_o |  |  |  |  | Ao | Length match datas |  | 312 | sdo_A_data_3_o | 4.0173 | 29.04249 | -0.86 | 2.2815 | -2.81023 | 5.79366
74 | 306 | -2.03 | 5.97 | C9 | -2.5 | 8.5 | sdo_A_data_0_o | 5.79812 | 0.70711 | 6.51 | 3.89 | 10.40 |  |  |  |  | Ao | 271 | sdo_A_data_0_o |  |  |  |  | Ao | Length match datas |  | 306 | sdo_A_data_0_o | 3.8949 | 20.966 | -0.62 | 2.2815 | -2.01366 | 5.91857
75 | 256 | 4.7 | 5.37 | A21 | 9.5 | 10.5 | sdo_B_tkn_ex_i | 7.11282 | 0.51478 | 7.63 | 4.45 | 12.08 | 1 | 1000 |  |  | Bo | 221 | sdo_B_tkn_ex_i | 1 | 1000 |  |  | Bo | Second prior, outer\second row | SDX_HIGH | 256 | sdo_B_tkn_ex_i | 4.4526 | 46.70809 | 1.42 | 2.2815 | 4.6609 | 5.33471
76 | 260 | 4.17 | 5.53 | C19 | 7.5 | 8.5 | sdo_B_data_7_o | 6.79663 | 0.57009 | 7.37 | 4.31 | 11.68 |  |  |  |  | Bo | 225 | sdo_B_data_7_o |  |  |  |  | Bo | Length match datas |  | 260 | sdo_B_data_7_o | 4.3101 | 41.9167 | 1.26 | 2.2815 | 4.13938 | 5.48874
77 | 268 | 3.11 | 5.78 | A18 | 6.5 | 10.5 | sdo_B_data_3_o | 6.74764 | 0.56569 | 7.31 | 4.07 | 11.38 |  |  |  |  | Bo | 233 | sdo_B_data_3_o |  |  |  |  | Bo | Length match datas |  | 268 | sdo_B_data_3_o | 4.0699 | 31.78873 | 0.94 | 2.2815 | 3.08397 | 5.74089
78 | 258 | 4.44 | 5.45 | A20 | 8.5 | 10.5 | sdo_B_sclk_ex_o | 6.90731 | 0.51478 | 7.42 | 4.38 | 11.80 | 1 | 1000 |  |  | Bo | 223 | sdo_B_sclk_ex_o | 1 | 1000 |  |  | Bo | Second prior, outer\second row | SDX_HIGH | 258 | sdo_B_sclk_ex_o | 4.3796 | 44.33558 | 1.34 | 2.2815 | 4.40072 | 5.41405
79 | 264 | 3.64 | 5.66 | B19 | 7.5 | 9.5 | sdo_B_data_5_o | 6.52708 | 0.70711 | 7.23 | 4.18 | 11.42 |  |  |  |  | Bo | 229 | sdo_B_data_5_o |  |  |  |  | Bo | Length match datas |  | 264 | sdo_B_data_5_o | 4.1822 | 36.94145 | 1.1 | 2.2815 | 3.61352 | 5.62415
80 | 272 | 2.57 | 5.88 | B17 | 5.5 | 9.5 | sdo_B_data_1_o | 7.06169 | 0.67268 | 7.73 | 3.97 | 11.71 |  |  |  |  | Bo | 237 | sdo_B_data_1_o |  |  |  |  | Bo | Length match datas |  | 272 | sdo_B_data_1_o | 3.974 | 26.47058 | 0.78 | 2.2815 | 2.55138 | 5.83891
81 | 270 | 2.84 | 5.84 | C16 | 4.5 | 8.5 | sdo_B_data_2_o | 6.39454 | 0.70711 | 7.10 | 4.02 | 11.12 |  |  |  |  | Bo | 235 | sdo_B_data_2_o |  |  |  |  | Bo | Length match datas |  | 270 | sdo_B_data_2_o | 4.0198 | 29.14936 | 0.86 | 2.2815 | 2.81801 | 5.79224
82 | 278 | 1.76 | 6 | A17 | 5.5 | 10.5 | sdo_B_token_i | 6.63849 | 0.5 | 7.14 | 3.87 | 11.01 | 1 | 1000 |  |  | Bo | 243 | sdo_B_token_i | 1 | 1000 |  |  | Bo | Second prior, outer\second row | SDX_HIGH | 278 | sdo_B_token_i | 3.8694 | 18.50224 | 0.52 | 2.2815 | 1.74793 | 5.95093
83 | 282 | 1.22 | 6.05 | A16 | 4.5 | 10.5 | sdo_B_sclk_i | 6.10866 | 0.70711 | 6.82 | 3.82 | 10.63 | 1 | 1000 |  |  | Bo | 247 | sdo_B_sclk_i | 1 | 1000 |  |  | Bo | Second prior, outer\second row | SDX_HIGH | 282 | sdo_B_sclk_i | 3.8166 | 12.87513 | 0.36 | 2.2815 | 1.21045 | 6.00216
84 | 266 | 3.38 | 5.73 | B18 | 6.5 | 9.5 | sdo_B_data_4_o | 6.09074 | 0.70711 | 6.80 | 4.12 | 10.92 |  |  |  |  | Bo | 231 | sdo_B_data_4_o |  |  |  |  | Bo | Length match datas |  | 266 | sdo_B_data_4_o | 4.1241 | 34.38665 | 1.02 | 2.2815 | 3.34916 | 5.68485
85 | 276 | 2.03 | 5.97 | B16 | 4.5 | 9.5 | sdo_B_ncmd_o | 6.07675 | 0.5 | 6.58 | 3.90 | 10.47 |  |  |  |  | Bo | 241 | sdo_B_ncmd_o |  |  |  |  | Bo | Length match datas |  | 276 | sdo_B_ncmd_o | 3.8956 | 21.00515 | 0.62 | 2.2815 | 2.01638 | 5.91822
86 | 274 | 2.3 | 5.93 | C15 | 3.5 | 8.5 | sdo_B_data_0_o | 6.02405 | 0.54083 | 6.56 | 3.93 | 10.50 |  |  |  |  | Bo | 239 | sdo_B_data_0_o |  |  |  |  | Bo | Length match datas |  | 274 | sdo_B_data_0_o | 3.9326 | 23.7549 | 0.7 | 2.2815 | 2.28414 | 5.8809
87 | 262 | 3.91 | 5.6 | C18 | 6.5 | 8.5 | sdo_B_data_6_o | 5.98832 | 0.53151 | 6.52 | 4.24 | 10.76 |  |  |  |  | Bo | 227 | sdo_B_data_6_o |  |  |  |  | Bo | Length match datas |  | 262 | sdo_B_data_6_o | 4.2443 | 39.45178 | 1.18 | 2.2815 | 3.87695 | 5.55878
88 | 90 | -4.85 | -5.32 | AB2 | -9.5 | -10.5 | sdo_C_tkn_ex_i | 7.25647 | 0.5 | 7.76 | 4.53 | 12.29 | 1 | 1000 |  |  | Co | 75 | sdo_C_tkn_ex_i | 1 | 1000 |  |  | Co | Second prior, outer\second row | SDX_HIGH | 90 | sdo_C_tkn_ex_i | 4.5317 | 48.46436 | -1.42 | -2.2815 | -4.81221 | -5.28643
89 | 106 | -2.77 | -5.85 | AB6 | -5.5 | -10.5 | sdo_C_data_2_o | 7.22637 | 0.70711 | 7.93 | 4.03 | 11.97 |  |  |  |  | Co | 91 | sdo_C_data_2_o |  |  |  |  | Co | Length match datas |  | 106 | sdo_C_data_2_o | 4.0335 | 29.08313 | -0.78 | -2.2815 | -2.74062 | -5.80648
90 | 98 | -3.82 | -5.62 | AA4 | -7.5 | -9.5 | sdo_C_data_6_o | 6.93349 | 0.70711 | 7.64 | 4.26 | 11.90 |  |  |  |  | Co | 83 | sdo_C_data_6_o |  |  |  |  | Co | Length match datas |  | 98 | sdo_C_data_6_o | 4.2552 | 39.13165 | -1.1 | -2.2815 | -3.78547 | -5.58224
91 | 92 | -4.59 | -5.4 | AB3 | -8.5 | -10.5 | sdo_C_sclk_ex_o | 7.08725 | 0.5 | 7.59 | 4.46 | 12.05 | 1 | 1000 |  |  | Co | 77 | sdo_C_sclk_ex_o | 1 | 1000 |  |  | Co | Second prior, outer\second row | SDX_HIGH | 92 | sdo_C_sclk_ex_o | 4.4579 | 46.19937 | -1.34 | -2.2815 | -4.55749 | -5.36703
92 | 102 | -3.29 | -5.75 | AA6 | -5.5 | -9.5 | sdo_C_data_4_o | 6.73357 | 0.70711 | 7.44 | 4.14 | 11.58 |  |  |  |  | Co | 87 | sdo_C_data_4_o |  |  |  |  | Co | Length match datas |  | 102 | sdo_C_data_4_o | 4.137 | 34.19425 | -0.94 | -2.2815 | -3.265 | -5.70337
93 | 114 | -1.69 | -6.01 | AB8 | -3.5 | -10.5 | sdo_C_token_i | 6.55579 | 0.70711 | 7.26 | 3.87 | 11.14 | 1 | 1000 |  |  | Co | 99 | sdo_C_token_i | 1 | 1000 |  |  | Co | Second prior, outer\second row | SDX_HIGH | 114 | sdo_C_token_i | 3.8725 | 18.24054 | -0.46 | -2.2815 | -1.67212 | -5.9594
94 | 112 | -1.96 | -5.98 | AA8 | -3.5 | -9.5 | sdo_C_ncmd_o | 6.45268 | 0.70711 | 7.16 | 3.91 | 11.07 |  |  |  |  | Co | 97 | sdo_C_ncmd_o |  |  |  |  | Co |  |  | 112 | sdo_C_ncmd_o | 3.9057 | 20.97306 | -0.54 | -2.2815 | -1.93795 | -5.92841
95 | 118 | -1.15 | -6.06 | AB9 | -2.5 | -10.5 | sdo_C_sclk_i | 6.58 | 0.53852 | 7.12 | 3.82 | 10.94 | 1 | 1000 |  |  | Co | 103 | sdo_C_sclk_i | 1 | 1000 |  |  | Co | Second prior, outer\second row | SDX_HIGH | 118 | sdo_C_sclk_i | 3.8194 | 12.69184 | -0.3 | -2.2815 | -1.13916 | -6.00762
96 | 108 | -2.5 | -5.9 | AA7 | -4.5 | -9.5 | sdo_C_data_1_o | 6.33596 | 0.70711 | 7.04 | 3.99 | 11.03 |  |  |  |  | Co | 93 | sdo_C_data_1_o |  |  |  |  | Co | Length match datas |  | 108 | sdo_C_data_1_o | 3.9877 | 26.46588 | -0.7 | -2.2815 | -2.47716 | -5.85125
97 | 100 | -3.56 | -5.69 | AA5 | -6.5 | -9.5 | sdo_C_data_5_o | 6.16074 | 0.70711 | 6.87 | 4.19 | 11.06 |  |  |  |  | Co | 85 | sdo_C_data_5_o |  |  |  |  | Co | Length match datas |  | 100 | sdo_C_data_5_o | 4.1943 | 36.68518 | -1.02 | -2.2815 | -3.52576 | -5.64505
98 | 94 | -4.34 | -5.48 | Y4 | -7.5 | -8.5 | sdo_C_data_8_o | 6.07295 | 0.70711 | 6.78 | 4.39 | 11.17 |  |  |  |  | Co | 79 | sdo_C_data_8_o |  |  |  |  | Co | Length match datas |  | 94 | sdo_C_data_8_o | 4.3871 | 43.88897 | -1.26 | -2.2815 | -4.30141 | -5.44321
99 | 96 | -4.08 | -5.55 | Y5 | -6.5 | -8.5 | sdo_C_data_7_o | 6.06114 | 0.70711 | 6.77 | 4.32 | 11.09 |  |  |  |  | Co | 81 | sdo_C_data_7_o |  |  |  |  | Co | Length match datas |  | 96 | sdo_C_data_7_o | 4.3195 | 41.53304 | -1.18 | -2.2815 | -4.04405 | -5.51496
100 | 104 | -3.03 | -5.8 | Y7 | -4.5 | -8.5 | sdo_C_data_3_o | 5.94883 | 0.70711 | 6.66 | 4.08 | 10.74 |  |  |  |  | Co | 89 | sdo_C_data_3_o |  |  |  |  | Co | Length match datas |  | 104 | sdo_C_data_3_o | 4.0834 | 31.65979 | -0.86 | -2.2815 | -3.00326 | -5.75719
101 | 110 | -2.22 | -5.94 | Y8 | -3.5 | -8.5 | sdo_C_data_0_o | 6.09624 | 0.57009 | 6.67 | 3.94 | 10.61 |  |  |  |  | Co | 95 | sdo_C_data_0_o |  |  |  |  | Co | Length match datas |  | 110 | sdo_C_data_0_o | 3.9432 | 23.67322 | -0.62 | -2.2815 | -2.20326 | -5.89285
102 | 160 | 4.87 | -5.31 | AB21 | 9.5 | -10.5 | sdo_D_tkn_ex_i | 7.23901 | 0.5 | 7.74 | 4.54 | 12.28 | 1 | 1000 |  |  | Do | 145 | sdo_D_tkn_ex_i | 1 | 1000 |  |  | Do | Second prior, outer\second row | SDX_HIGH | 160 | sdo_D_tkn_ex_i | 4.5413 | 48.66867 | 1.42 | -2.2815 | 4.83007 | -5.28062
103 | 158 | 4.61 | -5.4 | AB20 | 8.5 | -10.5 | sdo_D_sclk_ex_o | 7.08369 | 0.5 | 7.58 | 4.47 | 12.05 | 1 | 1000 |  |  | Do | 143 | sdo_D_sclk_ex_o | 1 | 1000 |  |  | Do | Second prior, outer\second row | SDX_HIGH | 158 | sdo_D_sclk_ex_o | 4.4665 | 46.39756 | 1.34 | -2.2815 | 4.57441 | -5.36185
104 | 144 | 2.78 | -5.85 | AB17 | 5.5 | -10.5 | sdo_D_data_1_o | 6.90334 | 0.70711 | 7.61 | 4.04 | 11.65 |  |  |  |  | Do | 129 | sdo_D_data_1_o |  |  |  |  | Do | Length match datas |  | 144 | sdo_D_data_1_o | 4.0375 | 29.24359 | 0.78 | -2.2815 | 2.75239 | -5.80438
105 | 152 | 3.83 | -5.62 | AA19 | 7.5 | -9.5 | sdo_D_data_5_o | 6.88627 | 0.70711 | 7.59 | 4.26 | 11.85 |  |  |  |  | Do | 137 | sdo_D_data_5_o |  |  |  |  | Do | Length match datas |  | 152 | sdo_D_data_5_o | 4.2615 | 39.31229 | 1.1 | -2.2815 | 3.79986 | -5.57864
106 | 156 | 4.35 | -5.48 | Y19 | 7.5 | -8.5 | sdo_D_data_7_o | 7.01401 | 0.56569 | 7.58 | 4.39 | 11.97 |  |  |  |  | Do | 141 | sdo_D_data_7_o |  |  |  |  | Do | Length match datas |  | 156 | sdo_D_data_7_o | 4.3949 | 44.08117 | 1.26 | -2.2815 | 4.31744 | -5.43861
107 | 148 | 3.31 | -5.74 | AA17 | 5.5 | -9.5 | sdo_D_data_3_o | 6.44677 | 0.70711 | 7.15 | 4.14 | 11.30 |  |  |  |  | Do | 133 | sdo_D_data_3_o |  |  |  |  | Do | Length match datas |  | 148 | sdo_D_data_3_o | 4.142 | 34.36417 | 0.94 | -2.2815 | 3.27797 | -5.7006
108 | 150 | 3.57 | -5.68 | AA18 | 6.5 | -9.5 | sdo_D_data_4_o | 6.42527 | 0.70711 | 7.13 | 4.20 | 11.33 |  |  |  |  | Do | 135 | sdo_D_data_4_o |  |  |  |  | Do | Length match datas |  | 150 | sdo_D_data_4_o | 4.2 | 36.86033 | 1.02 | -2.2815 | 3.53941 | -5.64189
109 | 140 | 2.24 | -5.94 | AA15 | 3.5 | -9.5 | sdo_D_ncmd_o | 6.38983 | 0.70711 | 7.10 | 3.95 | 11.05 |  |  |  |  | Do | 125 | sdo_D_ncmd_o |  |  |  |  | Do |  |  | 140 | sdo_D_ncmd_o | 3.9488 | 23.96274 | 0.62 | -2.2815 | 2.22376 | -5.88993
110 | 154 | 4.09 | -5.55 | Y18 | 6.5 | -8.5 | sdo_D_data_6_o | 6.55244 | 0.54083 | 7.09 | 4.33 | 11.42 |  |  |  |  | Do | 139 | sdo_D_data_6_o |  |  |  |  | Do | Length match datas |  | 154 | sdo_D_data_6_o | 4.3265 | 41.71938 | 1.18 | -2.2815 | 4.05923 | -5.51088
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

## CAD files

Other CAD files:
ucsd_bga_332/pcb/for_assembly_corwil/UCSD001-Bonding_2014-03-19.dwg

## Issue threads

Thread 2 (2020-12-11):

3x3mm Package for BSG_CHIP

yunusdawji, 2020-12-11:
Hi @drichmond @taylor-bsg ,

I am planning to implement a 3x3mm chip bsg bison. I see comments that ucsd_bga_332 has been used for 3x3mm chip. I have contacted the packaging house and it seems the max length of bondwire allowed is 6.5 mm.  My rough calculation tells me the max bondwire length needs to be 8mm for 3x3mm chip. So I was wondering how did you come over the issue of bondwire length limitation. Do you have modified version of ucsd_bsg_332?

All the help is really appreciated.

Regards,

Yunus

taylor-bsg, 2020-12-11:
Which wire is 8mm

On Fri, Dec 11, 2020 at 10:30 AM Yunus Dawji <notifications@github.com>
wrote:

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

yunusdawji, 2020-12-11:
Sorry calculation error :P. I think it will be ~6mm in worst case. I was doing 12.6mm-3mm=9.6 but it should be 9.6mm/2=4.8mm. Also I saw a comment GF14 pad ring has suggest fixes. Is there something is should be worried about?

Closed 2021-01-11.

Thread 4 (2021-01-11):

Packaging Base Material

yunusdawji, 2021-01-11:
Hi,

I am looking for cheaper alternatives for the packaging substrate. I see that N5000 and FR370HR have been used. I was wondering if there are cheaper more commonly used alternative? Also I see the chip need 30uin gold on top layer. I have in past used 2uin immersion gold (by mistake) and they bonded quite nicely. Do you think I could use 2uin or 3uin gold on top layer

Yunus

taylor-bsg, 2021-01-12:
How many substrates are you trying to make? most of the cost is in the NRE
anyway, but if you are planning to make 1000's, maybe it would make a
difference.

The gold used on the top is based on what the assembly house is okay with
-- usually there are a few emails between you, the assembly house and
package fab to resolve this. If you are the assembly house, then you can do
whatever you and the substrate fab agree to. =)

M

On Mon, Jan 11, 2021 at 2:21 PM Yunus Dawji <notifications@github.com>
wrote:

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

yunusdawji, 2021-01-12:
Thanks for the reply. I am looking to save whatever I can. If I do with pcbway.com, they are charging 1k for 100 boards but they don't any BT-epoxy based base material. We don't have big fundings right now, so whatever we can save is good.

We will most like use quickpak for wirebonding, so I will ask them.

taylor-bsg, 2021-01-12:
Well that would be cool if you can pull it off! Most packaging is optimized
for 10 year kinds of reliability and potential life or death consequences
of failure, and probably you need much less. In that case,...

I would ask the assembly house about whether there would be any issues in
attaching solder balls and bond wires to FR4 (or high temp FR4 if it is
better for them.)  The other issues are lower performance and less
reliability due to thermal expansion, but presumably those bond wires have
a little bit of flex in them.

On Mon, Jan 11, 2021 at 5:17 PM Yunus Dawji <notifications@github.com>
wrote:

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

yunusdawji, 2021-01-12:
Thanks for the ideas. Guys at PCB way suggested TU-862 HF. This material has similar Tg as N5000 and same permitivity. I will ask the ppl at quickpak if they can work with substrate. I will let you know how it goes.

yunusdawji, 2021-01-19:
Hi Prof.,

One more question. I see in an image that on BSG Motherboard has an ironwood reusable socket. How does that interface with chip packaging substrate and where can I buy this socket?

Yunus

taylor-bsg, 2021-01-20:
New material: cool!

Ironwood socket is custom, we can give you the part number. Tell  your
assembly house what the dimensions are when they do encapsulation. Socket
has some PCB decal pattern as direct attach, but you need a little more
space around it, and some holes for the retention clips.

M

On Tue, Jan 19, 2021 at 9:56 AM Yunus Dawji <notifications@github.com>
wrote:

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

yunusdawji, 2021-01-20:
Thanks for the reply. Yeah it would be great if you can give us the part number/datasheet for socket. We are using quickpak for assembly, so I think they will be familiar. But if you have dimensions for encapsulation, then that should be good aswell.

taylor-bsg, 2021-01-20:
If you are doing Quickpak then you are fine and can just wait until you are
packaging your die and we’ll give you all the info

On Tue, Jan 19, 2021 at 4:12 PM Yunus Dawji <notifications@github.com>
wrote:

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

yunusdawji, 2021-01-20:
Ok thanks! Our tapeout is in couple of days, so we should be there in soon.

taylor-bsg, 2021-01-20:
Good luck!

On Tue, Jan 19, 2021 at 4:20 PM Yunus Dawji <notifications@github.com>
wrote:

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

yunusdawji, 2021-02-26:
Hi,

I was wondering I could get access to this wiki. https://bitbucket.org/taylor-bsg/bsg_fpga/wiki/Home

We want to test our loopback board.

Thanks

Yunus

taylor-bsg, 2021-02-26:
Just to refresh my memory, what components are you using in the system?

On Thu, Feb 25, 2021 at 8:52 PM Yunus Dawji <notifications@github.com>
wrote:

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

yunusdawji, 2021-10-21:
Thanks for the reply! I see in one of the document there are bumps on underside but maybe its just illustration.

Also I see for uw bga you have ENIPIG finish in the stack up document. Can ENIPIG work?

https://github.com/bespoke-silicon-group/bsg_packaging/blob/master/uw_bga/pcb/UWCS001_BGA_A03_PAUL_MODIFIED_2_fab.pdf

taylor-bsg, 2021-10-22:
To be clear “assembly is king” — you ask the assembly house what they
require and then talk to the substrate fabrication house. Fabrication house
will tell what is convenient for them versus what assembly will want.

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

yunusdawji, 2021-10-22:
Sorry one more thing for the package substrate, are there solder balls on the underside of your chip? I dont see anything in this chip in youtube video.

gaozihou, 2021-10-22:
Hi @yunusdawji,
Yes, it needs 0.6mm solder balls on the underside of the BGA substrate to use the Ironwood socket.

yunusdawji, 2021-10-22:
Ok thanks.

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

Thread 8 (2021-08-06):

The python program bond_diagram_generator coundn't run properly

zhongpanwu, 2021-08-06:
Hello,
I am trying to run the bond_diagram_generator to have a padring diagram pdf file. However, both the scirpts draw_wire_binds.py and draw_die.py have a same problem that the line 19 in function csv_to_map complains about the out range of index, any help from you can help me solve this problem? Also, are there any documents from you about the tools and scripts which can share to me?  Thanks in advance.

taylor-bsg, 2021-08-06:
@stdavids

zhongpanwu, 2021-08-09:
Hello, I think I solved the problem, but I just have one more question. In the final bonding pad diagram (/to_assembly_house/example_files_for_assembly_house/final_combined.png), the first wire on the most left-bot side is off. So my questions are: 1, which pinout connects to it? 2, did you do it on purpose or corrected it manually before the submission to assembly house?  I am expecting to get any replication from you. Thanks.

zhongpanwu, 2021-08-09:
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

zhongpanwu, 2021-08-09:
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

taylor-bsg, 2021-08-09:
Hi, if you figured out a fixed, appreciate a pull request!

Regarding your question, I believe you are asking why the wire can be misaligned with the red mark. If you look at the picture of the package, the entire blue ring is exposed (no soldermask), so the bondhouse can actually bond anywhere on that ring as long as they don't short the wires together.   Generally speaking, the bondhouse takes the position of wires on the ring as a guidance rather than a requirement. This may be useful for them to get around hard cases.

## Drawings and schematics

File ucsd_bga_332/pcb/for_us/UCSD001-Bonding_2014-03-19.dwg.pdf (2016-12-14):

ZONE | REV | DESCRIPTION | DATE | APPROVED

## REVISIONS

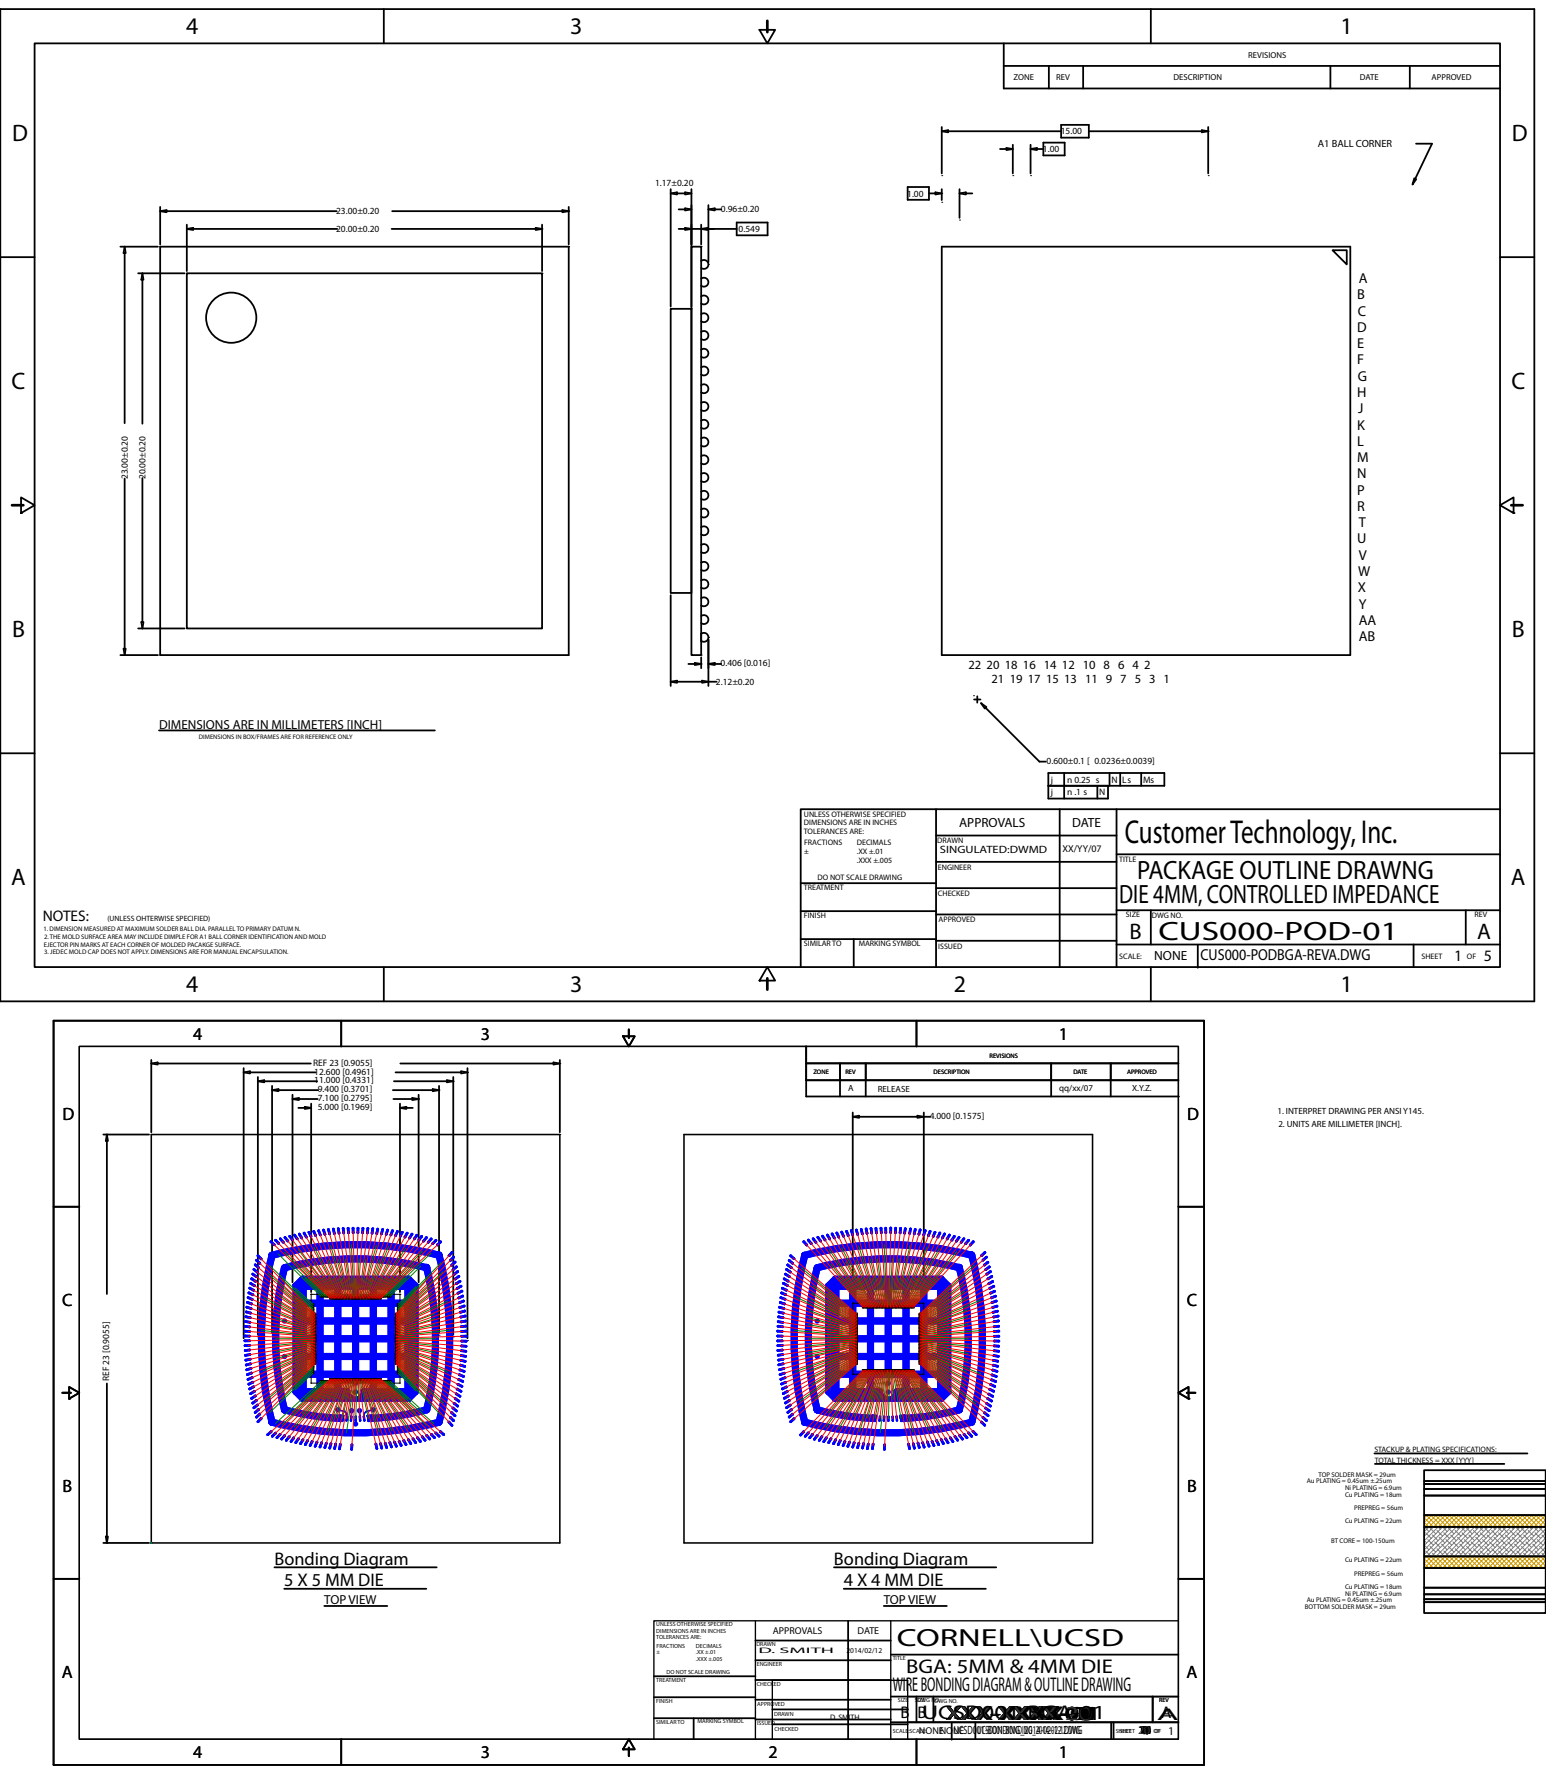
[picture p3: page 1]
RELEASE; OF CHECKED; ZONE; REV; DESCRIPTION; DATE; APPROVED; REVISIONS; SIZE; DWG NO.; SCALE:; SHEET; A NONE; UCSD001-BONDING_2014-02-12.DWG; XXX-XXXX-01 XXX-XXXX-02 XXX-XXXX-03 XXX-XXXX-04 XXX-XXXX-05 XXX-XXXX-06 XXX-XXXX-07 XXX-XXXX-08; XXX-XXXX-09 XXX-XXXX-10; XXX-XXXX-11 XXX-XXXX-12; XXX-XXXX-13 XXX-XXXX-14; XXX-XXXX-15 XXX-XXXX-16; XXX-XXXX-17 XXX-XXXX-18; XXX-XXXX-19 XXX-XXXX-20; APPROVALS; DECIMALS; .XXX ±.005; FINISH; SIMILAR TO; MARKING SYMBOL; ISSUED; UCSD001-BGA-01; CHECKED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

DIMENSIONS ARE IN MILLIMETERS [INCH] DIMENSIONS IN BOX/FRAMES ARE FOR REFERENCE ONLY

Customer Technology, Inc.
PACKAGE OUTLINE DRAWNG
TITLE
DIE 4MM, CONTROLLED IMPEDANCE

j | n 0.25 s | N Ls | Ms
j | n .1 s | N

UNLESS OTHERWISE SPECIFIED
DIMENSIONS ARE IN INCHES
TOLERANCES ARE:
FRACTIONS

DRAWN SINGULATED:DWMD | XX/YY/07

ENGINEER

DO NOT SCALE DRAWING
TREATMENT

NOTES: (UNLESS OHTERWISE SPECIFIED)

1. DIMENSION MEASURED AT MAXIMUM SOLDER BALL DIA. PARALLEL TO PRIMARY DATUM N.
2. THE MOLD SURFACE AREA MAY INCLUDE DIMPLE FOR A1 BALL CORNER IDENTIFICATION AND MOLD
EJECTOR PIN MARKS AT EACH CORNER OF MOLDED PACAKGE SURFACE.
3. JEDEC MOLD CAP DOES NOT APPLY. DIMENSIONS ARE FOR MANUAL ENCAPSULATION.

1. INTERPRET DRAWING PER ANSI Y145.
2. UNITS ARE MILLIMETER [INCH].

STACKUP & PLATING SPECIFICATIONS:
TOTAL THICKNESS = XXX [YYY]

TOP SOLDER MASK = 29um Au PLATING = 0.45um ±.25um Ni PLATING = 6.9um

Bonding Diagram
5 X 5 MM DIE TOP VIEW

4 X 4 MM DIE TOP VIEW
CORNELL\UCSD
BGA: 5MM & 4MM DIE
WIRE BONDING DIAGRAM & OUTLINE DRAWING

Ni PLATING = 6.9um Au PLATING = 0.45um ±.25um
BOTTOM SOLDER MASK = 29um

DRAWN D. SMITH | 2014/02/12

CHECKED | | B

APPROVED
DRAWN D. SMITH

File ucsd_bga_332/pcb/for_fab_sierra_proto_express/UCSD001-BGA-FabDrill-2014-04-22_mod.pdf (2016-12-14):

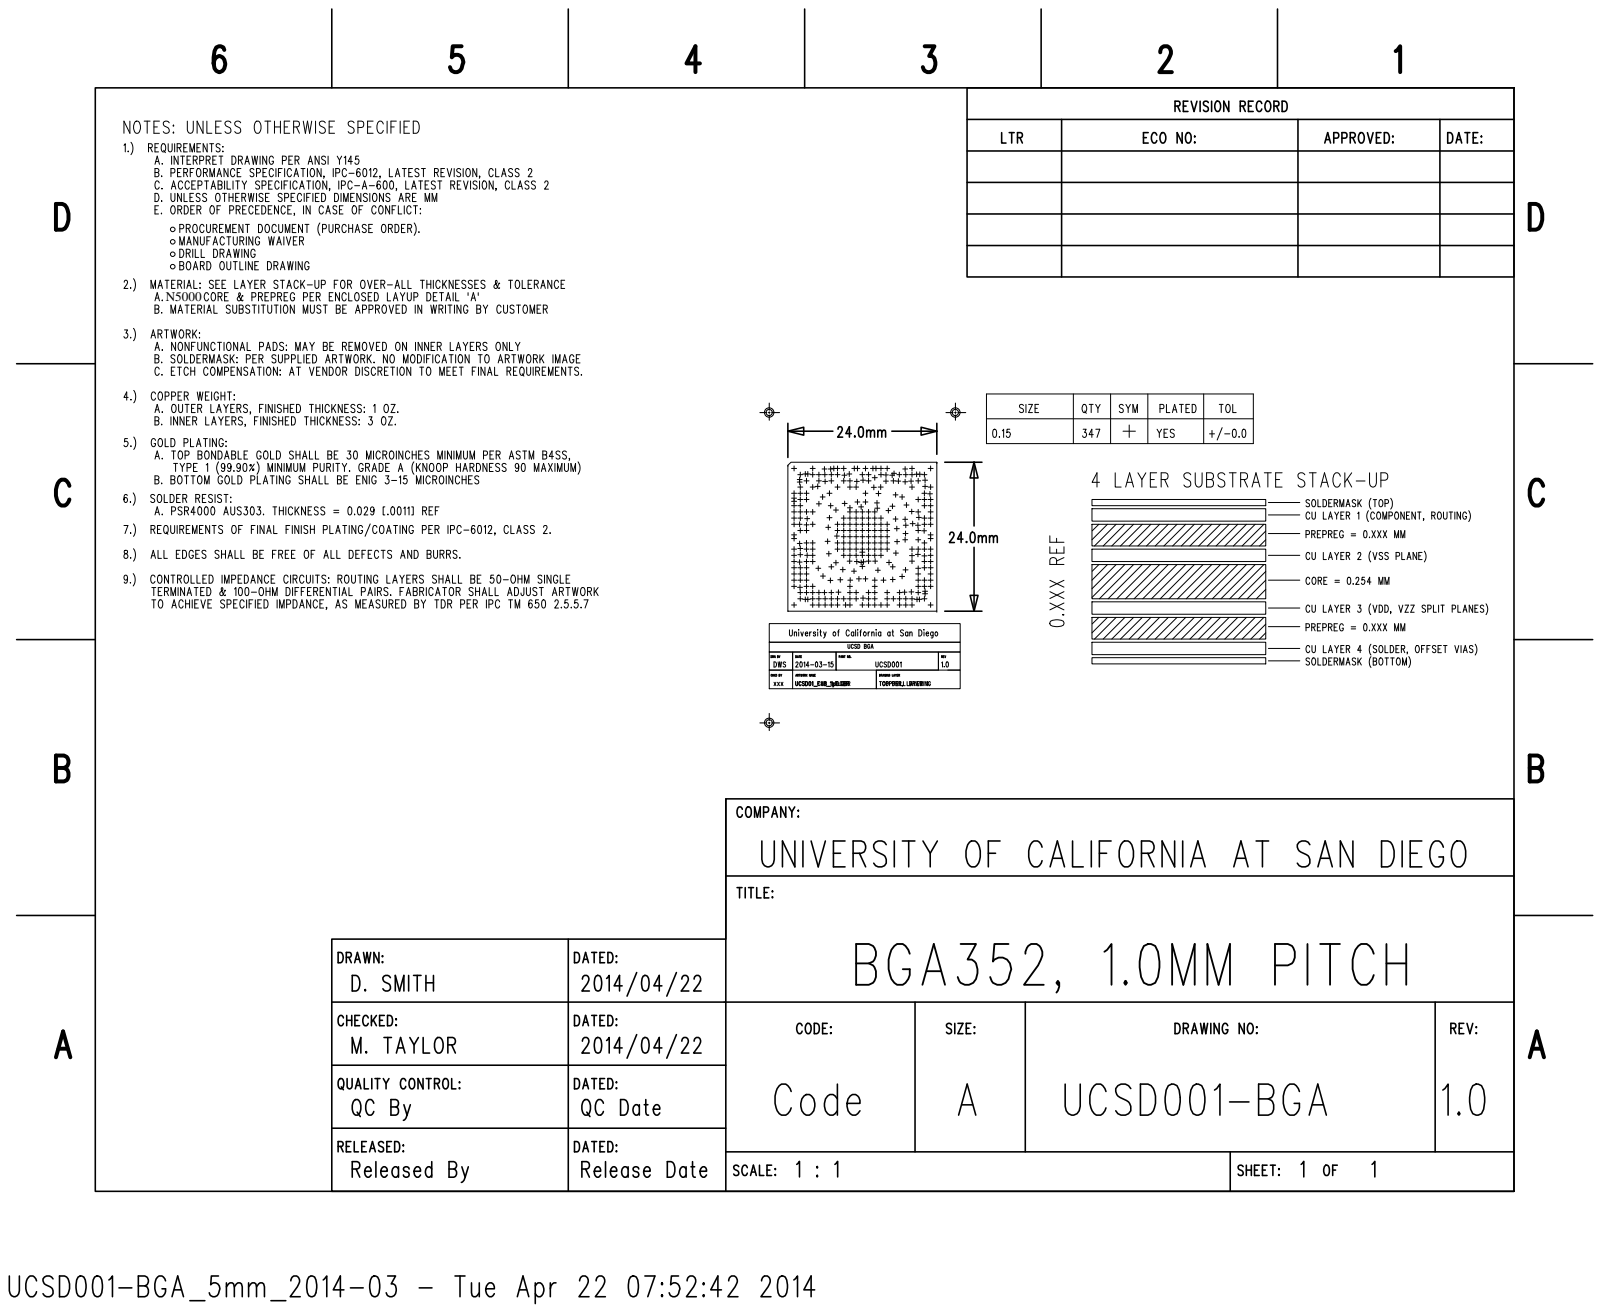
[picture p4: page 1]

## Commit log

2016-08-07 add 7 pin bus decl
2016-09-10 make clock output pin normal slew
2016-09-15 copy pin-pad constraint and added whitespace
2016-09-15 switching filler and corner pads to 180 cells
2016-09-15 adding python script for pad ring generation
    [io_pads.csv]
2016-09-16 tsmc180 moved pll power pads to analog power pads
2016-09-23 updating tcl generation script
    [bsg_two_centroid.csv, bsg_two_centroid_rotate.csv, io_pads.csv]
2016-09-24 adjusting tsmc180 padring to match expanded die area
2016-10-10 swap core VDD and VSS pads in PLL digital power domainn to input signal pads
2016-10-21 moved back to power pads
2016-12-14 add pcb specific files
    [UCSD001-Bonding_2014-03-19.dwg, UCSD001-DesignInfo-2014-03-15.xlsx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]
2017-01-06 adding csv with coordinates between bsg_two and bga substrate
    [ucsd_bga_5x5_bsg_two_to_substrate.csv]
2017-01-14 moved substrate coordinates to prevent overlaping
    [ucsd_bga_5x5_bsg_two_to_substrate.csv]
2017-02-02 major structural change
    [bsg_two_centroid.csv, bsg_two_centroid_rotate.csv, ucsd_bga_5x5_bsg_two_to_substrate.csv]
2017-02-23 adding layer column to ucsd_bga_5x5_bsg_two_to_substrate.csv
    [ucsd_bga_5x5_bsg_two_to_substrate.csv]
2017-03-08 -adding harvard bump assignment and an io ring that matches it - supporting 2.5x2.5 with a veriolog define switch - updating physical io pad definitions to match with harvard
2017-03-09 Fixing DVDDTIE instantiation that can cause innovus to crash during power planning
2017-04-09 Adding new padring power that has a fixed bump routing to every peripheral IO. It also includes preliminary plans for LDO and PLL islands
    [certus.xlsx]
2017-04-10 Updated for IO margin and PLL cut section
2017-04-11 Updates for LDO power sections
2017-04-19 Updating the analog IOs to use the 500Ohm pad output Updating the PLL SPI signals to use new toplevel IOs Cleaned up unused IOs Re-did placement of some IO cells to help with routing
2017-04-24 Removed power pins from RTL when instantiating LDO ports Added extra power suppy for LDO Fixed several padring related issues
2017-04-26 adding bsg_three pinout. Right now, this is a copy of the current state of tsmc_16 in bsg_two which will be reverted when this branch is merged with master.
    [bsg_two_centroid.csv, bsg_two_centroid_rotate.csv, certus.xlsx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]
2017-04-26 Switching orientation of some IO cells that have been moved around
2017-04-29 Updated to address more MBT concerns Changing power/corner cells to logical cells (required by cpf)
2017-05-05 Updated pin mapping spreadsheet
    [certus.xlsx]
2018-04-03 Adding placement for VDDOUT_LDO (LDO power output) on the ring and bump mapping
2018-04-09 - Removing power net wire from synthesis. It causes issues with implemenation
